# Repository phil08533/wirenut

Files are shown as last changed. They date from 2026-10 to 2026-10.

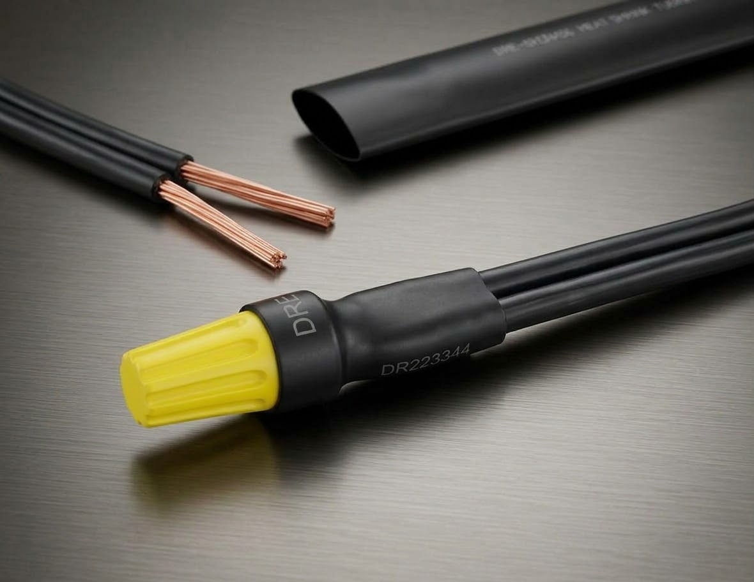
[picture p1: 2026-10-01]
IMAGES/reference_installed_on_wire_with_tubing.jpg

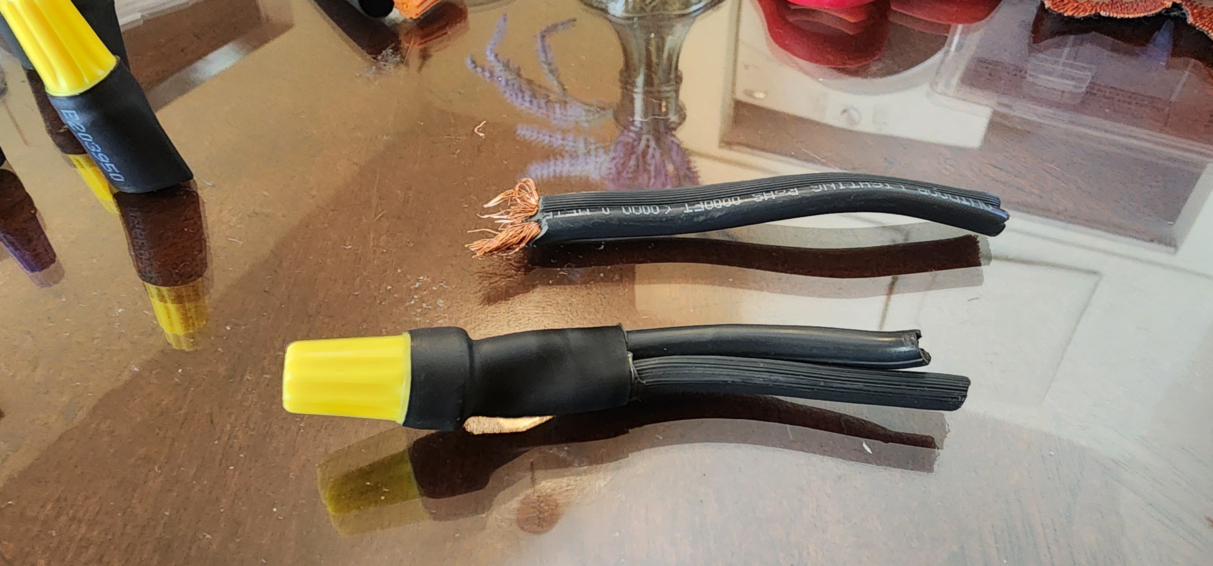
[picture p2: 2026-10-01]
IMAGES/original_installed_on_zip_cord.jpg

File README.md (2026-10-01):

# Waterproof Heat-Shrink Wire Nut — OEM Design Package

**Product:** Twist-on wire connector with integrated adhesive-lined heat-shrink waterproof sealing system.
**Primary market:** Outdoor low-voltage landscape lighting connections (12–15 V), with a path to 600 V general-purpose rating.
**IP status:** Provisional patent filed. Working prototype built (standard wire nut + heat-shrink tubing).
**Package status:** PRE-CAD. The design is NOT final. This package converts the prototype concept into a CAD-ready, quotable specification. Open items that must be resolved before tooling are tracked in `/OPEN_QUESTIONS`.

---

## Package structure

| Folder | Contents |
|---|---|
| `/PATENT` | Novelty analysis, claim language, alternative embodiments, design-around and China IP strategy, and **`05_application_draft/`** — the complete filing-ready non-provisional application (specification, 20 claims, abstract, 8 figures, forms guide) with a step-by-step pro se Patent Center filing walkthrough |
| `/ENGINEERING` | Concept trade study (Concepts A–D), selected product architecture, design calculations, materials specification |
| `/CAD_REQUIREMENTS` | Part breakdown (BOM), critical dimensions and tolerances, drawing package requirements, preliminary parametric CAD model (OpenSCAD) |
| `/MANUFACTURING` | Manufacturing plan (molding, tooling, assembly), China sourcing playbook, RFQ template, quality control plan |
| `/TESTING` | Validation test plan (UL 486D-oriented), certification roadmap |
| `/OPEN_QUESTIONS` | Questions the inventor must answer before CAD is finalized |
| `/IMAGES` | Prototype photos (AI-edited versions marked; originals to be added) |

## How to use this package

1. Answer everything in `/OPEN_QUESTIONS/01_questions_for_inventor.md`.
2. Lock the concept selection in `/ENGINEERING/01_concept_trade_study.md` (Concept A is recommended for launch; Concept B is the stronger long-term design — see the trade study).
3. Have a mechanical engineer or CAD contractor turn `/CAD_REQUIREMENTS` into production drawings (STEP + 2D PDF with GD&T).
4. Execute the IP steps in `/PATENT/04_design_around_and_ip_strategy.md` **before** sending anything to a Chinese factory (NNN agreement + non-provisional/PCT filing timing).
5. Send `/MANUFACTURING/03_rfq_template.md` plus the drawing package to 3–5 factories for quotation.
6. Validate first articles against `/TESTING/01_validation_test_plan.md`.

## Critical-path warnings

- **Provisional patent expires 12 months from filing.** The non-provisional application is drafted and ready in `/PATENT/05_application_draft/` — follow `00_pro_se_filing_walkthrough.md` to file it yourself before that date, and ideally before disclosure to any factory.
- **Never share this package with a Chinese supplier without a signed NNN agreement** (non-disclosure, non-use, non-circumvention, Chinese-law, Chinese-language). An ordinary US NDA is close to worthless in China.
- **UL 486D (Sealed Wire Connector Systems) is the certification that makes this product sellable** through distribution in the US. Design decisions in this package are made with 486D requirements in mind.

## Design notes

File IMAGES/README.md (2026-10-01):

# Prototype Images

Photos of the inventor's own prototypes: a standard twist-on wire nut combined with separately purchased heat-shrink tubing (parts from Harbor Freight).

## Originals (use these for filings, test records, and pitches)

| File | Shows |
|---|---|
| `original_lineup_prototypes.jpg` | Yellow (large) and blue (small) wire nuts with shrunk-on black heat-shrink sleeves, next to loose tubing and a lighter used for shrinking. |
| `original_installed_on_zip_cord.jpg` | Yellow wire nut with shrunk-on sleeve over spliced landscape-lighting zip cord, beside a stripped length of the same cord. |

The printed text on the sleeves (e.g. "E203950") is real. It is a UL file number printed by the tubing manufacturer and covers the tubing as a component only. It does NOT mean the finished connector is UL-listed.

## AI-edited versions

`reference_*.jpg` are the originals run through an AI image editor to look like studio shots. Use for mockups only, never for filings, test records, or buyer pitches.

TODO: record the date each original photo was taken.

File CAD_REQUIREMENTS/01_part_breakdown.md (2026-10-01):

# Part Breakdown / Engineering BOM

Assembly: **WNW-XX Waterproof Wire Nut, sealed twist-on connector** (XX = Y, R, XL)

## Top-level BOM (Concept A launch configuration)

| Item | Part no. | Description | Qty | Make/Buy | Drawing needed |
|---|---|---|---|---|---|
| 1 | WNW-XX-100 | Wire nut, twist-on, UL 486C listed | 1 | BUY | Source-control drawing (envelope + spec, not detail) |
| 2 | WNW-XX-200 | Sleeve, heat shrink, dual-wall 4:1, cut to length | 1 | BUY (cut by factory) | Detail drawing (tube spec + cut length + tolerance) |
| 3 | WNW-XX-000 | Assembly, sleeve tacked to nut | — | MAKE | Assembly drawing + tack process spec |
| 4 | WNW-PKG-25 | Bag, printed, 25-count | 1/25 | BUY | Artwork file |
| 5 | WNW-INS-01 | Instruction insert | 1/bag | BUY | Artwork file |

## Concept B additions (gen-2 — model now for patent figures, tool later)

| Item | Part no. | Description | Qty | Make/Buy |
|---|---|---|---|---|
| 6 | WNW-XX-110 | Shell, molded PA66, integral shrink-anchor skirt (annular barb ring + extended skirt) | 1 | MAKE (injection mold) |
| 7 | WNW-XX-120 | Spring, square-wire, tapered coil | 1 | BUY |

## Concept D additions (backup)

| Item | Part no. | Description | Qty | Make/Buy |
|---|---|---|---|---|
| 8 | WNW-XX-130 | Collar, snap-on shrink anchor, PA66 | 1 | MAKE (small mold) |

## Part-numbering and revision rules

- 7-segment: family (WNW) – size (Y/R/XL) – item (3 digit). Revisions letter-coded (A, B, …); any dimension change after tooling = new revision + PPAP-style re-approval.
- CAD file names must match part numbers exactly. One part per file; assembly files reference, never embed.

## Deliverable CAD file set (what the CAD contractor must produce)

| File | Format | Purpose |
|---|---|---|
| WNW-XX-000 assembly | STEP AP214 + native (SolidWorks preferred) | OEM quoting, tooling DFM |
| WNW-XX-100 envelope | STEP + PDF drawing | Source control for purchased nut |
| WNW-XX-200 detail | PDF drawing | Tube cut spec |
| WNW-XX-110 (Concept B shell) | STEP + PDF with full GD&T | Patent figures now; mold quote later |
| Exploded view | PDF + high-res PNG | Patent figures, instructions, marketing |
| 2D installation sequence (4 panels, mirrors prototype Figures 0–3) | PDF | Instruction insert + patent method figures |

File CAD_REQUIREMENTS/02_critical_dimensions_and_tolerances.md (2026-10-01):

# Critical Dimensions & Tolerances

Status: PRELIMINARY — values marked (V) require verification against the chosen purchased nut and rated cable set before drawings are released.

Units: primary **mm**, reference inches in brackets (Chinese factories work metric; the US-inch measurements from the prototype are converted here).

## D1. Purchased wire nut — source-control envelope

| Dim | WN-Y | WN-R | WN-XL | Tol | Critical? |
|---|---|---|---|---|---|
| Base OD (skirt) | 13.72 [0.540] | 16.00 [0.630] | 18.29 [0.720] | ±0.25 | **CTQ** — sets tubing supplied ID and tack interference |
| Overall height | 24.38 [0.960] | 26.67 [1.050] | 30.48 [1.200] | ±0.50 | No |
| Tip OD | 3.81 [0.150] | 4.57 [0.180] | 5.08 [0.200] | ±0.30 | No |
| Internal bore at base | 4.57 [0.180] | 5.59 [0.220] | 6.60 [0.260] | ±0.15 | **CTQ** — wire capacity |
| Internal taper angle | 6.5° | 6.5° | 6.5° | ±0.5° | **CTQ** — spring engagement |
| Skirt cylindrical band height (tack landing) | ≥ 6.0 | ≥ 6.0 | ≥ 7.0 | min | **CTQ** — tack zone must land on cylinder, not on wings |
| Wing/rib lowest point above skirt bottom | ≥ 7.0 | ≥ 7.0 | ≥ 8.0 | min | **CTQ** — clearance for tack tooling |

## D2. Heat-shrink sleeve (cut piece, supplied state)

| Dim | WN-Y | WN-R | WN-XL | Tol |
|---|---|---|---|---|
| Supplied ID | 16.0 | 20.0 | 24.0 | +1.0/−0 |
| Fully recovered ID (free) | ≤ 4.0 | ≤ 5.0 | ≤ 6.0 | max |
| Recovered wall (incl. adhesive) | ≥ 1.0 | ≥ 1.1 | ≥ 1.2 | min |
| Cut length | 30.0 | 33.0 | 36.0 | +1.0/−0 |
| Cut squareness | ≤ 1.0 | ≤ 1.0 | ≤ 1.0 | max deviation |

## D3. Assembly (shipped state) — CTQs measured at final QC

| Dim | Spec | Why |
|---|---|---|
| Sleeve top edge to nut top | tack zone starts 1.0 ± 0.5 mm below wing root | Wings stay usable |
| Tack zone length | 6.0 ± 1.0 (7.0 ± 1.0 XL) | Retention vs open bell |
| Bell ID after tack (at cut end) | ≥ 90% supplied ID | Wire insertion unobstructed |
| Sleeve axial retention | ≥ 20 N | Survives handling/pockets |
| Free bell length below nut mouth | ≥ 20 mm (Y), 22 (R), 24 (XL) | ≥15 mm sealed jacket length after 10% longitudinal shrink |
| Concentricity, sleeve to nut axis | ≤ 1.0 TIR | Cosmetic + even shrink |

## D4. Concept B molded shell (model now; toleranced for future tooling)

| Feature | Dim | Tol | Note |
|---|---|---|---|
| Anchor ring OD (barb crest) | skirt OD + 1.6 | ±0.10 | Tubing hooks behind this |
| Anchor groove root OD | skirt OD − 0.4 | ±0.10 | |
| Barb back-angle | 45° lead-in / 90° retention face | ±2° | Slide-on easy, pull-off hard |
| Skirt extension below standard profile | +4.0 | ±0.2 | Extra seal landing |
| Wall thickness (general) | 1.5 | ±0.1 | Moldability PA66 |
| Draft, external | ≥ 1° | min | Along mold pull |
| Draft, internal cone | taper itself (6.5°) serves as draft | — | Core pulls straight |
| Internal thread/spring geometry | copy qualified 486C design | — | Do NOT innovate here; certification risk |

## General tolerance block (for all drawings)

- Linear: ISO 2768-m (medium) unless stated.
- Molded parts: add shrinkage note — PA66 shrink 1.5–2.0%, tool maker to compensate; critical dims steel-safe.
- All CTQ dims must appear in the factory's control plan with Cpk ≥ 1.33 requirement.

## Measurement notes

- Recovered ID/wall measured per UL 224 method after 3 min at 150 °C oven.
- Retention force: pull sleeve axially off nut at 50 mm/min; record peak.

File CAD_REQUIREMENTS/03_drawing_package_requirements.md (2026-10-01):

# Drawing Package & Exploded-View Requirements

What the CAD contractor must deliver so an OEM can quote without a phone call.

## 1. Exploded view requirements

One exploded view per SKU (WNW-XX-000), isometric, axis vertical, nut tip up:

1. Wire nut (item 1) — show spring as cutaway inset.
2. Heat-shrink sleeve (item 2) — shown in supplied (expanded) state, translucent so the adhesive liner is visible as a distinct layer; callout "adhesive liner".
3. Phantom-line wire bundle entering from below (3 conductors shown).
4. Balloon numbers keyed to the BOM table on the same sheet.
5. Second state inset: "as shipped" (sleeve tacked) and "as installed" (recovered onto wires) — mirrors prototype Figures 0–3.

Also produce a **4-panel installation sequence** (strip/twist/heat/done) reusing the same models — this single set of geometry feeds the patent figures, the UL instruction insert, and packaging art.

## 2. Sheet requirements (every drawing)

- A3 landscape, third-angle projection, mm primary / inch reference.
- Title block: part no., rev, material, finish, scale, "CONFIDENTIAL — PATENT PENDING" legend.
- General tolerance block per 02_critical_dimensions_and_tolerances.md.
- CTQ dimensions boxed and flagged ◆ with note "CTQ — include in control plan, Cpk ≥ 1.33".
- Notes section must include manufacturing notes below.

## 3. Manufacturing notes to place on drawings

**WNW-XX-200 (sleeve):**
- Cut ends square within 1.0 mm; no adhesive smear on cut face.
- No slitting, printing, or handling above 60 °C prior to assembly.
- Supplier must provide UL 224 file no. and per-lot shrink-ratio coupon test.

**WNW-XX-000 (assembly):**
- Tack per process spec WNW-PS-001 (hot-air ring, 95–105 °C, 4–8 s, mandrel-supported).
- Full adhesive activation in tack zone NOT permitted (bell must remain open).
- 100% visual: sleeve position, no bridging of bell, no scorch.
- Retention audit: 20 N axial, AQL 1.0 sampling.

**WNW-XX-110 (Concept B shell, when tooled):**
- PA66, UL 94 V-2 min, UL-recognized resin (f1 outdoor grade if colored).
- Gate on tip face; no gate vestige > 0.2 mm; parting line flash ≤ 0.05 mm on skirt sealing band and anchor ring.
- Spring insertion after molding; torque-out and pull test per UL 486C.

## 4. File deliverables

| Deliverable | Format |
|---|---|
| 3D models | Native (SolidWorks 2022+ preferred) + STEP AP214 |
| 2D drawings | PDF + native |
| Exploded/sequence art | PDF + PNG (3000 px) |
| Patent-figure line art | Derived from CAD, black line art, no shading (patent draftsman can convert) |

## 5. Preliminary geometry in this repo

`wirenut_preliminary.scad` (OpenSCAD, parametric, all three SKUs + Concept B anchor ring) is included as a **starting reference only** — it encodes the target dimensions so the CAD contractor starts from numbers, not a sketch. It is not a production model: no spring geometry, no draft analysis, purchased-nut envelope only.

Render:  `openscad -D 'sku="XL"' -o wnw-xl.stl wirenut_preliminary.scad`

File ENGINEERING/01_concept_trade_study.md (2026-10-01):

# Concept Trade Study — Waterproof Sealing System Architecture

Question: **How should the waterproof heat-shrink system attach to the wire nut?**

Four concepts evaluated. Scoring: 1 (worst) to 5 (best). Weighting reflects the stated goal: a product that installs like a normal wire nut, seals reliably, and can be mass produced and quoted by an OEM quickly.

---

## Concept A — Pre-installed heat-shrink sleeve on a standard (purchased) wire nut

Adhesive-lined heat-shrink tubing is factory-installed over the skirt of an off-the-shelf UL-listed wire nut and extends past the wire entry. Installer twists the nut on as normal, then heats the sleeve (lighter, mini-torch, or heat gun). Adhesive flows around the wire jackets and the nut skirt, forming the seal and strain relief. **This is the prototype as built (Figures 0–3).**

- The tubing must be retained on the nut before shrinking. Options: (1) partial factory pre-shrink of the top ~1/4 of the sleeve onto the nut skirt ("tacked" state — this is what the prototype drawing shows), (2) a bead of the same adhesive, or (3) buying nuts with a molded skirt lip and pre-shrinking over it.
- No custom plastic tooling. The only custom items are the cut-to-length tubing spec and the assembly fixture.

| Criterion | Score | Notes |
|---|---|---|
| Manufacturing cost | 5 | No injection mold. Purchased nut ($0.02–0.05) + tubing ($0.04–0.10) + assembly labor/fixture. Landed COGS est. $0.10–0.20/unit at 100k volume. |
| Patent strength | 3 | Combination of known elements; strength depends on claiming the pre-assembled/tacked state, retention feature, and geometry (see /PATENT). Easier to design around than B. |
| Ease of assembly (factory) | 4 | Cut tube, slide over nut, partial pre-shrink in fixture (hot air ring or IR oven), inspect. Simple semi-automated line. |
| Factory complexity | 5 | Any cable-accessory or heat-shrink converter in China can do this. No mold trial, no resin qualification. |
| Installer experience | 4 | Identical to a wire nut + one heating step. |
| Certification path | 3 | The purchased nut is already UL 486C listed; the *sealed system* still needs UL 486D testing as a new product. Using a listed nut shortens testing. |

**Total (unweighted): 24/30 — RECOMMENDED FOR LAUNCH.**

## Concept B — Custom-molded wire nut with integral shrink-anchor skirt

A custom injection-molded nut (own tooling, own spring insert) whose lower skirt is extended and features a molded retention profile — an annular barb/groove ring — specifically shaped to anchor adhesive-lined heat shrink. Tubing is factory-installed over the anchor ring.

| Criterion | Score | Notes |
|---|---|---|
| Manufacturing cost | 3 | Mold: $8k–25k (multi-cavity), spring sourcing, insert or post-assembly of spring. COGS est. $0.08–0.15 at volume — cheaper per unit than A eventually, but high NRE. |
| Patent strength | 5 | The molded anchor geometry is a claimable structural feature; hardest to design around. |
| Ease of assembly | 4 | Same tubing operation as A, but retention is positive (mechanical) — more robust process window. |
| Factory complexity | 3 | Needs a molder + spring insertion + shrink assembly. Standard for Yueqing-area connector factories but adds mold trials, DFM loops. |
| Installer experience | 4 | Same as A. |
| Certification path | 2 | Entire connector must pass UL 486C **and** 486D from scratch (spring design, flammability, torque tests). |

**Total: 21/30 — RECOMMENDED AS GENERATION 2** and as the **primary patent embodiment** (file claims covering it now even though launch uses A).

## Concept C — Fully custom molded waterproof housing (no heat shrink)

A custom housing sealing by mechanical means — e.g., silicone-gel pre-fill, twist-compressed grommet, or O-ring cap. No heat step.

| Criterion | Score | Notes |
|---|---|---|
| Manufacturing cost | 2 | Multiple molded parts, gel dispensing or elastomer overmold; COGS $0.20–0.40. |
| Patent strength | 1 | Crowded prior art: gel-filled twist connectors (King DryConn), 3M DBY/DBR direct-bury kits, WAGO gel boxes. High freedom-to-operate risk. |
| Ease of assembly | 2 | Gel dispensing lines or multi-part assembly. |
| Factory complexity | 2 | Most complex of the four. |
| Installer experience | 3 | No heat needed (a plus), but gel is messy and re-entry is unpleasant. |
| Certification path | 3 | Well-trodden 486D territory. |

**Total: 13/30 — REJECTED.** This is where the entrenched competition already lives; it abandons the invention's differentiator.

## Concept D — Standard wire nut + separate custom molded sleeve adapter + heat shrink

A small molded collar snaps over a standard nut's skirt; the collar carries the shrink-anchor profile and the pre-installed tubing.

| Criterion | Score | Notes |
|---|---|---|
| Manufacturing cost | 3 | Small simple mold ($3k–8k) + purchased nut + tubing; COGS $0.13–0.25. |
| Patent strength | 4 | The adapter collar is a distinct, claimable article ("retrofit" claims are valuable — the collar could even be sold alone). |
| Ease of assembly | 3 | One extra snap-on operation; collar-to-nut fit depends on the purchased nut's tolerances (risk: nut vendor changes skirt geometry). |
| Factory complexity | 4 | Simple mold + assembly. |
| Installer experience | 4 | Same as A. |
| Certification path | 3 | Similar to A. |

**Total: 21/30 — STRONG BACKUP.** Choose D over A if pre-shrink tacking proves unreliable in process trials, or if a retrofit SKU (collar sold separately) is commercially interesting.

---

## Recommendation

1. **Launch with Concept A** (matches the working prototype, zero mold NRE, fastest to first article and UL 486D submission).
2. **Draft the patent around Concept B's anchor geometry as the primary embodiment**, with A and D as alternative embodiments, so the IP covers where the product will go, not just where it starts.
3. Run a **process trial during factory sampling**: if the pre-shrink tack on a smooth purchased-nut skirt slips in drop/handling tests, switch to Concept D's collar without changing the customer-facing product.

## Decision log

| Date | Decision | Status |
|---|---|---|
| — | Concept selection (A vs D for launch) | OPEN — pending inventor sign-off and process trial |
| — | Gen-2 custom nut (Concept B) go/no-go | OPEN — revisit after first 100k units |

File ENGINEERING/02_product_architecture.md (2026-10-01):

# Product Architecture — Concept A (Launch Configuration)

Status: PRELIMINARY — dimensions and features below are engineering targets derived from the prototype and measurement set. Final values require answers in `/OPEN_QUESTIONS` and factory DFM feedback.

## Product family (3 SKUs)

| SKU | Base nut (reference) | Nut base OD | Nut height | Wire range | Typical use |
|---|---|---|---|---|---|
| WN-Y (Yellow) | Standard yellow 74B-type | 0.54 in / 13.7 mm | 0.96 in / 24.4 mm | min 2×#18, max 4×#14+1×#18 | Fixture leads to run wire |
| WN-R (Red) | Standard red 76B-type | 0.63 in / 16.0 mm | 1.05 in / 26.7 mm | min 2×#14, max 2×#10+1×#12 | Main run splices |
| WN-XL (Oversized, custom target) | New size | 0.72 in / 18.3 mm | 1.20 in / 30.5 mm | up to 3×#10 | Heavy 10 ga landscape runs |

Note: WN-XL exceeds common off-the-shelf twist-on capacity for 3×#10; it may require a purchased gray/blue large-capacity nut (e.g., 454-type) or become the first custom-molded part (pulls Concept B forward for this SKU only). Flagged in `/OPEN_QUESTIONS`.

## Assembly stack (as shipped)

```
        ┌────────────────┐
        │  WIRE NUT      │  ← purchased, UL 486C listed, spring-insert twist-on
        │  (cone body)   │
   ┌────┴────────────────┴────┐
   │  HEAT-SHRINK SLEEVE      │  ← adhesive-lined polyolefin, 3:1 or 4:1
   │  upper 25% factory-tacked│     upper zone pre-shrunk onto nut skirt
   │  onto nut skirt          │
   │                          │
   │  lower 75% at supplied ID│  ← open "bell" that the wire bundle passes
   │  (free, unshrunk)        │     through during twist-on
   └──────────────────────────┘
```

## Functional description

1. **Shipped state (Figure 0/1):** sleeve is captive on the nut. The open lower bell is large enough that the installer can insert and twist wires exactly like a bare wire nut. Nothing loose, nothing to lose.
2. **Installation:** strip wires per nut spec, twist nut on to full torque. Sleeve does not interfere (bell ID > max bundle + fingers clearance).
3. **Sealing (Figure 2):** installer applies heat (lighter/torch/heat gun, ~120 °C shrink). Sleeve recovers radially onto the wire jackets; the internal hot-melt adhesive (activates ~80 °C) flows into the wire interstices and bonds to nut skirt and wire insulation.
4. **Sealed state (Figure 3):** continuous adhesive seal from nut skirt to ~20 mm down the wire jackets. Adhesive fillet + recovered tubing provide strain relief (bundle flexure is carried by the tubing, not the twisted joint).

## Key design features and their functions

| Feature | Function | Design driver |
|---|---|---|
| Adhesive-lined tubing (not single-wall) | Moisture seal; fills gaps between individual wires | UL 486D moisture ingress; single-wall tubing does NOT seal multi-wire bundles |
| Factory tack zone (upper 25%) | Captive sleeve; correct axial position guaranteed | Assembly repeatability; the installer never positions the tube |
| Tack onto nut *skirt*, below wing/rib zone | Keeps grip wings usable for twist-on torque | Install must feel like a normal wire nut |
| Sleeve overhang past wire entry: ≥ 0.9 in / 23 mm free length | ≥ 15 mm of sealed length on wire jackets after longitudinal shrinkage (~10%) | Seal length and strain relief |
| Shrink ratio 3:1 minimum (4:1 for WN-Y and WN-XL) | Must recover from over-nut-skirt ID down to smallest 2-wire bundle | See calculations file |
| Adhesive: EVA-based hot melt, lap-shear ≥ 1.4 MPa on PVC/PE | Bond to wire insulation types used in landscape cable | Direct-bury cable jackets are PE — harder to bond than PVC; verify |
| Tubing UV-stabilized (carbon-black loaded), operating −40…+125 °C | Outdoor exposure | Outdoor/UL 746C(f1)-equivalent weathering |
| Optional: temperature-indicating paint stripe on sleeve | Changes color at full recovery temperature — visual "done" signal | Reduces under-heating field failures; also a patentable feature |

## Interfaces

- **Nut ↔ sleeve:** friction + adhesive tack from factory pre-shrink. Retention spec: sleeve shall not displace under 20 N axial pull or 1 m drop onto concrete (pre-installation).
- **Sleeve ↔ wires:** recovered tubing + adhesive. Seal spec: pass 486D water immersion; pull-out per UL 486C table for the wire combination.
- **Installer heat source:** must fully recover with a butane lighter in ≤ 15 s without scorching. Tubing wall selected accordingly (thin-wall 4:1 preferred over heavy dual-wall).

## What is intentionally NOT decided yet

- Purchased-nut vendor and exact model (drives skirt geometry and tack process window).
- Whether WN-XL uses a purchased nut or the first custom mold.
- Sleeve color/branding (carbon black is best for UV; color requires UV-stable pigment qualification).
- Temperature-indicator stripe: include in v1 or hold for v2.

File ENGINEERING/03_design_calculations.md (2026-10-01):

# Design Calculations — Sleeve Sizing, Shrink Ratios, Seal Geometry

Status: PRELIMINARY. Wire ODs are nominal THHN/landscape-cable values and MUST be verified against the actual cable types the product will be rated for (see /OPEN_QUESTIONS — landscape lighting cable has much thicker insulation than THHN).

## 1. Wire bundle diameters

Circumscribed diameter of n equal circles of diameter d:
- 2 wires: 2.000 × d
- 3 wires: 2.155 × d
- 4 wires: 2.414 × d
- 5 wires: 2.701 × d

Nominal insulated ODs (THHN, approximate — verify):

| AWG | OD (in) | OD (mm) |
|---|---|---|
| #18 | 0.105 | 2.7 |
| #14 | 0.111 | 2.8 |
| #12 | 0.128 | 3.3 |
| #10 | 0.164 | 4.2 |

Typical low-voltage direct-burial landscape cable (e.g., 12/2, 10/2 zip-style) single-conductor leg OD is larger: ~0.19–0.24 in (4.8–6.1 mm) per leg. **This, not THHN, is probably the governing case — confirm.**

Governing bundle diameters per SKU (THHN basis):

| SKU | Min bundle | Dia | Max bundle | Dia |
|---|---|---|---|---|
| WN-Y | 2×#18 | 0.210 in / 5.3 mm | 4×#14 + 1×#18 | ≈0.30 in / 7.6 mm |
| WN-R | 2×#14 | 0.222 in / 5.6 mm | 2×#10 + 1×#12 | ≈0.36 in / 9.1 mm |
| WN-XL | 2×#12 (assumed) | 0.256 in / 6.5 mm | 3×#10 | 0.353 in / 9.0 mm |

## 2. Required shrink ratio

The sleeve must satisfy BOTH:
- **Supplied (expanded) ID** ≥ nut skirt OD + 0.5–1.0 mm assembly clearance (it is slid over the nut base at the factory).
- **Fully recovered ID** ≤ 0.85 × minimum bundle diameter (need residual hoop compression; adhesive fills the rest).

| SKU | Nut base OD | Required supplied ID | Min bundle | Required recovered ID | Required ratio |
|---|---|---|---|---|---|
| WN-Y | 13.7 mm | ≥ 14.5 mm | 5.3 mm | ≤ 4.5 mm | ≥ 3.2 : 1 → **use 4:1** |
| WN-R | 16.0 mm | ≥ 17.0 mm | 5.6 mm | ≤ 4.8 mm | ≥ 3.5 : 1 → **use 4:1** |
| WN-XL | 18.3 mm | ≥ 19.5 mm | 6.5 mm | ≤ 5.5 mm | ≥ 3.5 : 1 → **use 4:1** |

Conclusion: **4:1 adhesive-lined polyolefin across all SKUs.** Standard commercial 4:1 dual-wall sizes that fit:

| SKU | Candidate tubing (supplied/recovered ID) | Wall (recovered) |
|---|---|---|
| WN-Y | 16 / 4 mm | ~1.0 mm |
| WN-R | 20 / 5 mm | ~1.1 mm |
| WN-XL | 24 / 6 mm | ~1.2 mm |

Notes:
- 3:1 tubing only works if the minimum wire configuration is restricted (e.g., WN-R limited to ≥ 3×#14). That trade-off is a labeling/marketing decision — see /OPEN_QUESTIONS.
- If the minimum config is 2 legs of direct-burial cable (~2 × 5.5 mm = 11 mm bundle), 3:1 20/6.5 mm tubing suffices for WN-R/XL and cost drops ~30%. **This is why the rated-cable question is the single most important open item.**

## 3. Sleeve length

Requirements: cover skirt tack zone (6 mm) + bridge the wire-entry mouth (≈ 4 mm) + sealed length on jacket (≥ 15 mm) + longitudinal shrinkage allowance (10%).

| SKU | Cut length (supplied) | Tack zone | Free bell length |
|---|---|---|---|
| WN-Y | 30 mm +1/−0 | 6 mm | 24 mm |
| WN-R | 33 mm +1/−0 | 6 mm | 27 mm |
| WN-XL | 36 mm +1/−0 | 7 mm | 29 mm |

## 4. Thermal compatibility check

| Item | Temperature | OK? |
|---|---|---|
| Tubing shrink onset / full recovery | ~90 °C / ~120 °C | — |
| Adhesive activation | ~80 °C | — |
| Wire nut shell (PA66) melt / short-term | 255 °C / 180 °C | ✅ margin vs 120 °C |
| Wire nut shell if PP | melt 160 °C, softens ~120 °C | ⚠️ marginal — prefer PA66 nuts; verify purchased nut resin |
| PVC wire insulation rating | 105 °C (THHN) | ⚠️ brief excursion during shrink is industry-accepted (same as any heat-shrink splice), but flame dwell must be limited — instructions requirement |
| PE direct-burial jacket | softens ~105–120 °C | ⚠️ same — keep flame moving |

Action: purchased-nut spec must state shell resin = PA66 (or verified ≥150 °C short-term). This goes in the incoming-material spec (/MANUFACTURING/04).

## 5. Pre-tack process window (factory)

- Tack zone target recovery: 30–50% diametral (snug on skirt, adhesive *not* fully activated — full activation would glue the bell shut edge).
- Process: hot-air ring or IR oven, 95–105 °C zone, 4–8 s, nut held tip-down on mandrel so the bell hangs free.
- Verification: 20 N axial retention; bell ID after tack ≥ 90% of supplied ID.

## 6. Strain relief estimate

Recovered dual-wall on the bundle acts as a cantilever sleeve. With 15 mm sealed length and ~1 mm wall polyolefin + adhesive fillet, expected pull-out contribution ≥ 50 N and flex-life improvement >10× vs bare nut (to be validated per /TESTING — UL 486C pull-out table governs the pass/fail numbers, e.g., #10 requires 80 lbf on the connector joint itself).

## 7. Cost model (rough, 100k units/SKU/yr, China EXW)

| Element | WN-Y | WN-R | WN-XL |
|---|---|---|---|
| Purchased nut | $0.025 | $0.035 | $0.06 (large nut) |
| Tubing (4:1 dual wall, cut) | $0.06 | $0.08 | $0.11 |
| Assembly + QC | $0.02 | $0.02 | $0.02 |
| Packaging (bag of 25 + card) | $0.01 | $0.01 | $0.015 |
| **EXW unit** | **≈$0.12** | **≈$0.15** | **≈$0.21** |

Retail comparators: gel-filled waterproof nuts sell at $0.50–1.20/unit street price — healthy margin room. Refine with real quotes via /MANUFACTURING/03_rfq_template.md.

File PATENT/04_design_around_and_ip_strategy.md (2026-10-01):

# Design-Around Protection & IP Strategy

## How a competitor will try to design around you — and the counter

| Design-around attempt | Counter (already in this package) |
|---|---|
| Ship nut and sleeve **separately in one package** ("kit") to dodge the captive/unitary claim | Kit embodiment #26 + method claim 3 (covers the twist-then-heat use regardless of shipped state) |
| Use **cold-shrink** sleeve instead of heat shrink | Embodiment #14 + draft claims using "heat-recoverable **or** elastically-recoverable" language where counsel allows |
| Use **mastic band** instead of adhesive lining | Embodiment #9; claim "sealant lining" generically in at least one independent claim |
| Put the sleeve on a **push-in (WAGO-style) connector** instead of a twist-on | Embodiment #17 — instruct counsel to draft at least one claim to "an electrical connector" generically |
| Change retention: glue bead, clamp ring, overmold | Embodiments #5, #6, #7 |
| Stepped/top-hat sleeve to avoid your shrink-ratio dependent claims | Embodiment #10 (and keep ratio limits in *dependent* claims only) |
| Manufacture and sell only in China / export around US patent | CN utility model + CN customs IP recordation (below) |

## Filing strategy & timeline

| When | Action | Why |
|---|---|---|
| NOW | Confirm provisional filing date; calendar the 12-month deadline with 60-day buffer | Everything hangs on this date |
| Before factory contact | Non-provisional drafted (or at least NNN executed + disclosure limited to provisional content) | Unprotected disclosure = free gift |
| ≤ month 12 | File US non-provisional claiming priority + PCT (or direct CN filing) | Preserves US + international rights |
| With CN counsel | **CN utility model** in parallel (grants in ~7–12 months, no substantive exam, cheap) | The only fast, enforceable right where your factory lives; deters the factory itself |
| After CN grant | Record with China customs (GACC) | Enables seizure of infringing exports at Chinese ports |
| Anytime (cheap) | US + CN **design patent** on shipped-state appearance | Blocks lookalike knockoffs on Amazon; Amazon takedowns accept design patents readily |
| Now | US + CN **trademark** on the brand name | China is first-to-file; squatters watch new US brands |

## Practical enforcement reality

- The utility patent's biggest commercial value at your stage: **Amazon Brand Registry / IP takedowns** and deterring US distributors from stocking clones — not litigation.
- Mark packaging "Patent Pending" now; after grant, virtual marking (URL) per 35 USC 287.
- Keep an evidence file: dated prototype photos (the Figure 0–3 sheet), lab notebook, factory correspondence — supports priority disputes and derivation claims.

## Trade-secret layer (complements patents)

Keep OUT of the patent (and out of any single factory's hands if possible):
- The exact tack process window (temperature/time/fixture design) — process trade secret.
- Adhesive formulation selection rationale and supplier qualification data.
- The QC golden-sample criteria.

## Budget

| Item | Est. |
|---|---|
| Prior-art + FTO search | $2–4k |
| US non-provisional (attorney) | $8–15k |
| PCT filing | $4–5k (defers national decisions 30 months) |
| CN utility model | $1–2k |
| US design patent | $1.5–2.5k |
| US + CN trademarks | $1–2.5k |

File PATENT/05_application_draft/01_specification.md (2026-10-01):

# UTILITY PATENT APPLICATION — SPECIFICATION

> Formatting note (delete before filing): This document follows 37 CFR 1.77 section order. Convert to DOCX for filing (avoids the non-DOCX surcharge): 1.5 or double spacing, 12-pt font, paragraph numbering [0001]… as shown, page numbers centered bottom. Claims and Abstract are filed as parts of the same specification document but must each start on a new page — they live in `02_claims.md` and `03_abstract.md`.

---

# SEALABLE TWIST-ON WIRE CONNECTOR WITH CAPTIVE HEAT-RECOVERABLE SLEEVE

## CROSS-REFERENCE TO RELATED APPLICATIONS

[0001] This application claims the benefit of U.S. Provisional Patent Application No. **[PLACEHOLDER — 63/XXX,XXX]**, filed **[PLACEHOLDER — DATE]**, titled **[PLACEHOLDER — provisional title]**, the entire contents of which are incorporated herein by reference.

## FIELD OF THE INVENTION

[0002] The present disclosure relates to electrical connectors, and more particularly to twist-on wire connectors provided with an integrated, heat-recoverable environmental sealing system for making moisture-resistant electrical splices, for example in outdoor low-voltage landscape lighting installations.

## BACKGROUND

[0003] Twist-on wire connectors, commonly called wire nuts, are among the most widely used devices for splicing electrical conductors. A typical twist-on connector includes a generally conical insulating shell containing a tapered helical spring. Stripped conductor ends are inserted into the open end of the shell, and the connector is rotated so that the spring draws the conductors together into a twisted, gas-tight mechanical and electrical joint. Twist-on connectors are inexpensive, fast to install, require no tools, and are familiar to virtually every electrician and homeowner.

[0004] Standard twist-on connectors, however, provide no environmental seal. The open end of the shell leaves the splice exposed to moisture. In outdoor applications — landscape lighting, irrigation systems, well pumps, exterior fixtures — moisture ingress causes corrosion of the conductors and spring, increased contact resistance, galvanic degradation, nuisance failures, and, in low-voltage lighting systems, voltage drop and flickering.

[0005] Several approaches exist for sealing such splices, each with significant shortcomings. (a) Electrical tape wrapped over the connector and wires is slow, skill-dependent, unsightly, and unwinds or admits moisture over time. (b) Dielectric grease applied into the connector cavity is messy and provides no mechanical retention of the seal. (c) Pre-filled sealant connectors, in which the shell is factory-filled with silicone gel, provide useful moisture resistance but are messy to install and re-enter, provide little or no strain relief to the conductor bundle, and the gel can be displaced during installation, particularly with multiple large conductors. (d) Heat-shrinkable tubing with an adhesive lining is highly effective for sealing linear splices such as crimped butt connectors, but is fundamentally incompatible with twist-on connectors as conventionally supplied: the tubing must be threaded onto a conductor **before** the joint is made, must then be slid over the completed joint, and a twist-on connector is substantially larger in diameter than the conductor bundle, so tubing sized to pass over the connector cannot recover tightly onto the conductors unless a very high shrink ratio is used and the tubing is correctly positioned — a multi-step, error-prone process requiring the installer to select, cut, thread, park, position, and recover a separate component. In addition, the rotation of a twist-on connector during installation tends to displace or wind up any loose sleeve placed over it beforehand.

[0006] There accordingly exists a need for a wire connector that installs with the identical, familiar motion of a standard twist-on connector — with nothing extra to select, thread, or position — and that can then be environmentally sealed in a single additional step, providing both moisture sealing and strain relief, and that is manufacturable at low cost at scale.

## SUMMARY

[0007] The present disclosure provides a sealable electrical connector assembly in which a heat-recoverable, sealant-lined sleeve is factory-installed on a twist-on wire connector in a partially recovered, captive state. A first portion of the sleeve is recovered (or otherwise retained) onto an exterior skirt of the connector shell, permanently locating the sleeve on the connector. A second portion of the sleeve extends beyond the open end of the connector in a substantially unrecovered state, defining an open entry bell. Because the bell's inner diameter substantially exceeds the conductor bundle diameter, conductors are inserted and the connector is rotated exactly as with a standard twist-on connector; the captive sleeve neither obstructs insertion nor winds up during rotation. After the twisted joint is made, the installer applies heat; the second portion recovers radially onto the conductor insulation, and the sealant lining flows into the interstices between conductors and bonds to both the shell and the conductor insulation, forming a continuous environmental seal and a strain-relieving collar in one step.

[0008] In some embodiments the connector shell includes a molded annular retention formation — for example a barb ring having an inclined lead-in surface and a transverse retention surface — dimensioned to mechanically retain the sleeve against axial displacement and against the torsional loads of rotational installation. In other embodiments the sleeve is carried by a collar engageable with the skirt of a standard connector shell, permitting the sealing system to be applied to existing connector designs. Further embodiments include a stepped-diameter sleeve reducing the required shrink ratio; a thermochromic indicator that changes appearance when full recovery temperature has been reached, giving the installer positive visual confirmation of a complete seal; elastically recoverable (cold-shrink) sleeves held expanded by a removable core; and mastic or other sealant linings.

[0009] The assembly is supplied as a unitary article. Installation requires no additional parts, no threading of tubing before splicing, and no repositioning; the only step added to conventional practice is the application of heat. Embodiments described herein are dimensioned to seal conductor combinations from two 18 AWG conductors up to three 10 AWG conductors, including dissimilar-size combinations common in landscape lighting.

## BRIEF DESCRIPTION OF THE DRAWINGS

[0010] FIG. 1 is an exploded perspective view of a sealable connector assembly according to a first embodiment, showing a twist-on wire connector, a heat-recoverable sleeve, and a plurality of conductors.

[0011] FIG. 2 is a longitudinal cross-sectional view of the assembly of FIG. 1 in the as-supplied (shipped) state, showing the first sleeve portion recovered onto the shell skirt and the second sleeve portion defining an open entry bell.

[0012] FIG. 3 is a longitudinal cross-sectional view of the assembly of FIG. 1 in the installed and sealed state, recovered onto the conductors.

[0013] FIG. 4 is an enlarged fragmentary cross-sectional view of a second embodiment in which the connector shell includes an annular retention formation.

[0014] FIG. 5 is a cross-sectional view of a third embodiment in which the sleeve is carried by a collar engageable with the skirt of a standard twist-on connector.

[0015] FIGS. 6A–6D are sequential elevation views illustrating a method of forming a sealed connection using the assembly: FIG. 6A, conductor insertion; FIG. 6B, rotational installation; FIG. 6C, application of heat; FIG. 6D, the completed sealed connection.

[0016] FIG. 7 is a cross-sectional view of a further embodiment employing a stepped-diameter sleeve.

[0017] FIG. 8 is an elevation view of a further embodiment including a thermochromic recovery indicator.

## DETAILED DESCRIPTION

### First embodiment — captive pre-tacked sleeve (FIGS. 1–3)

[0018] Referring to FIGS. 1 and 2, a sealable connector assembly 10 comprises a twist-on wire connector 20 and a heat-recoverable sleeve 40 captively retained thereon. The connector 20 comprises an insulating shell 22 — for example molded polyamide — having an open end 24 communicating with an internal tapered cavity 26 in which a tapered helical spring 28 of square-section steel wire is retained. The shell 22 has a generally conical exterior narrowing from a base skirt portion 30 adjacent the open end 24 toward a closed tip, and carries external grip formations 32 (wings or ribs) by which installation torque is applied. The connector 20 may be of conventional construction and, in some embodiments, is a commercially available connector certified to applicable wire-connector standards.

[0019] The sleeve 40 is a tube of heat-recoverable, cross-linked polyolefin having an interior sealant lining 46, for example a hot-melt adhesive having an activation temperature (e.g., about 80 °C) below the full-recovery temperature of the sleeve (e.g., about 120 °C). The sleeve 40 comprises a first portion 42 and a second portion 44. The first portion 42 is partially recovered onto the skirt portion 30, gripping the shell and axially and rotationally locating the sleeve 40 on the connector 20. In this embodiment the partial recovery of the first portion 42 is performed during manufacture ("tacking"), for example by directing heated air at only the first portion while the second portion is shielded or spaced from the heat source, such that the sealant lining 46 within the first portion is not fully activated and the second portion 44 remains substantially at its expanded, as-supplied diameter.

[0020] The first portion 42 is recovered onto a substantially cylindrical band of the skirt portion 30 located below the grip formations 32, so that the grip formations remain exposed and fully usable for rotational installation. In one embodiment the first portion has an axial length of about 6 mm to about 7 mm and begins about 1 mm below the root of the grip formations 32.

[0021] The second portion 44 extends beyond the open end 24 and terminates at a distal end 48, defining an open entry bell whose inner diameter is substantially the as-supplied inner diameter of the sleeve — greater than the outer diameter of the skirt portion 30 and several times greater than the diameter of the largest rated conductor bundle. Conductors 50 having stripped ends 52 and insulation 54 are therefore insertable through the bell into the cavity 26 without contacting or displacing the sleeve, and the connector may be rotated to form the joint without the sleeve winding up, because the sleeve is fixed to the shell and rotates with it.

[0022] Referring to FIG. 3, after the twisted joint is formed, heat applied to the second portion 44 — by a lighter, torch, or hot-air tool — causes it to recover radially onto the insulation 54 of the conductors 50, forming a seal region 60 in which the activated sealant lining 46 flows into the interstices between adjacent conductors and forms a fillet 62 bonding the shell 22, the sleeve 40, and the insulation 54 into a continuous moisture barrier. The recovered second portion additionally couples bending loads on the conductor bundle into the shell rather than into the twisted joint, providing strain relief.

### Dimensional relationships

[0023] The sleeve is selected such that (a) its as-supplied inner diameter exceeds the outer diameter of the skirt portion 30, permitting factory assembly over the shell, and (b) its fully recovered inner diameter is no greater than about 85% of the diameter of the smallest conductor bundle the connector is rated to receive, ensuring residual hoop compression on the smallest bundle. For representative connector sizes these conditions correspond to a diametral shrink ratio of at least about 3:1, and in the embodiments tabulated below, about 4:1.

[0024] Table 1 sets forth representative, non-limiting dimensions for three embodiment sizes:

| Parameter | Size 1 | Size 2 | Size 3 |
|---|---|---|---|
| Shell base (skirt) outer diameter | 13.7 mm (0.54 in) | 16.0 mm (0.63 in) | 18.3 mm (0.72 in) |
| Shell overall height | 24.4 mm (0.96 in) | 26.7 mm (1.05 in) | 30.5 mm (1.20 in) |
| Cavity bore at open end | 4.6 mm (0.18 in) | 5.6 mm (0.22 in) | 6.6 mm (0.26 in) |
| Cavity taper angle (per side) | ~6–7° | ~6–7° | ~6–7° |
| Rated conductor range | 2×18 AWG to 4×14+1×18 AWG | 2×14 AWG to 2×10+1×12 AWG | up to 3×10 AWG |
| Sleeve as-supplied ID | 16 mm | 20 mm | 24 mm |
| Sleeve fully recovered ID | ≤ 4 mm | ≤ 5 mm | ≤ 6 mm |
| Sleeve cut length | 30 mm | 33 mm | 36 mm |
| First (tacked) portion length | 6 mm | 6 mm | 7 mm |

[0025] In embodiments, the second portion 44 is dimensioned such that, after full recovery and accounting for longitudinal shrinkage of about 10%, the sleeve extends at least about 15 mm along the conductor insulation beyond the open end 24, providing the seal region 60 with sufficient length for both sealing and strain relief.

### Second embodiment — shell with retention formation (FIG. 4)

[0026] Referring to FIG. 4, in a second embodiment the shell 22 is molded with an annular retention formation 70 on the skirt portion 30. The retention formation 70 comprises an inclined lead-in surface 72 facing away from the open end 24, over which the sleeve is slid during factory assembly, and a transverse retention surface 74 facing toward the open end, behind which the first portion 42 of the sleeve engages. In one embodiment the lead-in surface 72 is inclined at about 30° to about 60° to the shell axis and the retention surface 74 is substantially perpendicular to the shell axis, and the formation projects radially about 0.8 mm above the adjacent skirt surface. The retention formation positively resists both axial pull-off and rotational slip during installation torque, widening the manufacturing process window: with the formation 70, the first portion 42 may be recovered only lightly, or the sleeve may even be retained by the formation alone without thermal tacking. The shell of this embodiment may further include an extended skirt 76 lengthening the sealing land. The retention formation may alternatively comprise a groove, a plurality of ribs, knurling, or other surface texture performing the equivalent retaining function.

### Third embodiment — retrofit collar (FIG. 5)

[0027] Referring to FIG. 5, in a third embodiment the sleeve 40 is carried by a collar 80 having resilient engagement features 82 (for example an interference band or snap fingers) engageable with the skirt of a standard, unmodified twist-on connector 20. The collar 80 carries the retention geometry of the second embodiment, and the sleeve 40 is retained on the collar with its second portion 44 defining the entry bell as previously described. This embodiment permits the sealing system to be supplied either pre-assembled to a connector or as a separate adapter for field or factory application to existing connectors.

### Method of use (FIGS. 6A–6D)

[0028] Referring to FIGS. 6A–6D, a sealed connection is formed by: providing the assembly 10 as a unitary article; inserting stripped ends 52 of two or more conductors 50 through the open bell of the second portion 44 into the cavity 26 (FIG. 6A); rotating the connector 20 by the grip formations 32 to draw the conductors into a twisted mechanical and electrical joint, the sleeve rotating with the connector (FIG. 6B); applying heat from a heat source 110 — an open flame, hot-air tool, or other source — to the second portion 44 until it recovers onto the conductor insulation and the sealant lining activates (FIG. 6C); and allowing the assembly to cool, yielding a sealed, strain-relieved connection (FIG. 6D). Notably, steps illustrated in FIGS. 6A and 6B are identical to the installation of a conventional twist-on connector; no tubing is selected, cut, threaded, parked, or positioned by the installer.

### Further embodiments

[0029] **Stepped sleeve (FIG. 7).** The sleeve 40 may be a stepped-diameter member 100 having a smaller-diameter proximal region pre-formed to approximately the skirt diameter and a larger-diameter distal bell, reducing the shrink ratio required of the distal region and permitting use of lower-ratio, lower-cost tubing while preserving the captive, open-bell installation behavior.

[0030] **Recovery indicator (FIG. 8).** The sleeve 40 may carry a thermochromic indicator 90 — a stripe, dot, or full-surface coating — that irreversibly changes appearance upon reaching substantially the full-recovery temperature of the sleeve, providing the installer visual confirmation that sealing temperature was achieved and reducing under-heated field failures.

[0031] **Sealant variants.** The sealant lining 46 may comprise a hot-melt adhesive, a mastic band disposed within the second portion, a UV-curable or chemically activated sealant, or combinations thereof. In embodiments, the lining is confined to, or of greater thickness in, the second portion 44, so that factory tacking of the first portion does not activate sealant unnecessarily.

[0032] **Elastic (cold-shrink) variant.** The sleeve 40 may be an elastically recoverable elastomeric sleeve held in a radially expanded state by a removable core, the core extending through the second portion; withdrawal of the core after installation recovers the second portion onto the conductors without applied heat. All references herein to a "heat-recoverable" sleeve should be understood to encompass, in the alternative, such elastically recoverable sleeves except where heating is expressly recited.

[0033] **Connector variants.** While the illustrated connector is a twist-on connector with helical spring 28, the captive-sleeve sealing system may be applied to other insulation-piercing, push-in, lever-actuated, or crimp connectors having a shell with an exterior surface onto which the first portion 42 can be retained. The shell may be molded with the sleeve in place (insert molding), or the sleeve may be retained by an adhesive bead, a clamp ring, or the collar of the third embodiment.

[0034] **Materials.** In embodiments the shell 22 comprises polyamide (e.g., PA66) rated for the recovery temperature of the sleeve; the sleeve comprises cross-linked polyolefin, ultraviolet-stabilized for outdoor exposure, for example carbon-black loaded; and the sealant lining comprises an ethylene-vinyl-acetate-based hot-melt adhesive bonding to polyvinyl chloride, polyethylene, and polyamide surfaces. These materials are exemplary and non-limiting.

[0035] **Kit form.** The connector and sleeve may alternatively be supplied unassembled as a kit in a common package, the sleeve including an alignment feature cooperating with the shell to establish the captive shipped configuration described above upon assembly by the user.

[0036] The embodiments described above are illustrative. Features of any embodiment may be combined with features of any other. The scope of the invention is defined by the claims, not by the particular examples given, and equivalents of the claimed elements are intended to be embraced thereby.

---

## REFERENCE NUMERAL INDEX (drafting aid — delete before filing)

| # | Element | # | Element |
|---|---|---|---|
| 10 | sealable connector assembly | 48 | distal end of sleeve |
| 20 | twist-on wire connector | 50 | conductors |
| 22 | shell | 52 | stripped ends |
| 24 | open end | 54 | insulation |
| 26 | internal tapered cavity | 60 | seal region |
| 28 | helical spring | 62 | sealant fillet |
| 30 | skirt portion | 70 | retention formation |
| 32 | grip formations | 72 | lead-in surface |
| 40 | heat-recoverable sleeve | 74 | retention surface |
| 42 | first portion (tacked) | 76 | extended skirt |
| 44 | second portion (bell) | 80 | collar |
| 46 | sealant lining | 82 | engagement features |
| — | — | 90 | thermochromic indicator |
| — | — | 100 | stepped sleeve |
| — | — | 110 | heat source |

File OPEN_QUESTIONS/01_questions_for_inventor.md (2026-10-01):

# Open Questions for the Inventor

These must be answered before the CAD drawings are released. Items marked 🔴 block CAD; 🟡 block RFQ; 🟢 block certification/launch. Answer inline under each question and commit.

## 1. Prototype construction 🔴

1.1 Which exact wire nut brand/model did the working prototype use (brand, size/color, purchased where)?
1.2 Which exact heat-shrink tubing (brand, supplied/recovered diameter, 2:1/3:1/4:1, adhesive-lined or single-wall)?
1.3 How is the tubing attached to the nut in your prototype — pre-shrunk at the top (as Figure 0–3 suggests), glued, or just friction? Has it ever slipped off in handling?
1.4 How many prototypes built, and have any been water-tested? Results?

## 2. Heat-shrink placement 🔴

2.1 In the shipped state, how far up the nut does the tubing sit — does it cover the grip wings/ribs, or stop below them? (Drives tack-zone location; current assumption: stops below the wings so twist grip is unaffected.)
2.2 After shrinking, how much tubing length is on the wires? (Current target ≥ 15 mm — confirm against what worked.)

## 3. Sealing method 🔴

3.1 Is your prototype tubing adhesive-lined? If not: single-wall tubing will NOT pass water immersion on a multi-wire bundle — the package assumes adhesive-lined dual-wall. Confirm you accept this change.
3.2 Do you want a **re-enterable** connection (cut sleeve off, re-splice with a new unit) as a documented procedure, or is single-use acceptable? (Affects instructions and marketing, not geometry.)

## 4. Wire entry / rated conductors 🔴 — **the single most important question set**

4.1 What actual cable will customers use — THHN singles, or 2-conductor direct-burial landscape cable (12/2, 10/2)? Landscape cable legs are much fatter (~5–6 mm each); this drives shrink ratio, recovered ID, and possibly the whole tubing selection (see ENGINEERING/03 §2).
4.2 What is the **minimum** wire combination each SKU must seal? (Smallest bundle drives the required shrink ratio; if we can set min = 2×#14, tubing cost drops.)
4.3 For WN-XL (3×#10): is this THHN #10 or #10 landscape cable legs?
4.4 Must the product seal mixed combinations (e.g., 1 fat landscape leg + 1 thin fixture lead #18)? That asymmetry is the hardest seal case.

## 5. Installation process 🟡

5.1 What heat source should the instructions assume as primary: butane lighter, micro-torch, or heat gun? (Field reality for landscapers = lighter/torch; affects tubing wall spec and scorch testing.)
5.2 Acceptable install time budget for the heating step (current target ≤ 15 s)?
5.3 Should v1 include the temperature-indicator stripe ("turns black when sealed"), or hold for v2? Adds ~$0.01–0.02/unit and one supplier qualification.
5.4 Any requirement to install in rain/wet conditions? (Adhesive won't bond to wet jackets — instructions issue.)

## 6. Materials 🟡

6.1 Sleeve color: black (best UV, recommended) or match nut color (yellow/red — needs UV-stable pigment qualification, cost adder)?
6.2 Any objection to sourcing tubing from qualified Chinese makers (Woer/Volsun grade) vs TE/Panduit (2–4× cost)?
6.3 For Concept A: do you have a preferred wire-nut brand to buy, or should the factory propose its UL-listed source (cheapest, but adds a supplier-change risk clause)?

## 7. Voltage rating & claims 🟢

7.1 Target marketing claim: low-voltage only (12–30 V landscape) or full 600 V splice rating? (Nut supports 600 V; the difference is test scope and instruction wording.)
7.2 Direct-bury claim: yes/no? (Big label value for landscape; adds 486D burial testing. Recommend YES.)
7.3 Target markets beyond US: Canada (cUL — cheap adder, recommend yes)? EU (different connector culture, suggest defer)?

## 8. Business/commercial 🟢

8.1 Provisional filing date? (Sets the non-provisional deadline — everything in PATENT/04 hangs on it.)
8.2 Does the provisional describe the pre-tacked captive sleeve state and the anchor-ring variant, or only "wire nut + heat shrink" generally? (Determines how urgent the non-provisional is.)
8.3 Brand name for trademark filing (US + CN)?
8.4 Launch channel: Amazon/DTC first, or distribution/big-box? (Changes UL-vs-ETL choice and packaging.)
8.5 Budget envelope for the next 12 months? (Package assumes roughly: IP $15–25k, certification $20–45k, pilot inventory $8–12k, misc $5k.)

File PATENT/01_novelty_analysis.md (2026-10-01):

# Novelty Analysis

**Disclaimer:** Engineering analysis to prepare you for patent counsel — not legal advice. A professional prior-art/FTO search by a patent attorney is a required next step.

## Prior-art landscape (what already exists)

| Category | Examples | How it seals | Relevance |
|---|---|---|---|
| Gel/silicone pre-filled twist connectors | King Innovation DryConn, Ideal WeatherProof, Gardner Bender WeatherProof | Dielectric silicone grease pre-filled in oversized shell | Closest commercial competitors; heavily patented historically (many now expired) — crowds Concept C, not the heat-shrink approach |
| Direct-bury splice kits | 3M DBY/DBR, King DryConn Direct Bury | Wire nut inserted into a separate gel-filled tube | Two-piece, bulky, no heat |
| Heat-shrink crimp splices | NSPA/Molex "Krimpa-Seal", generic sealed butt splices | Adhesive-lined tubing over a **crimp** barrel | Establishes adhesive-lined shrink as known for *crimps* — not for twist-on connectors |
| Separate heat-shrink tubing | Any brand | Installer cuts and slides tubing **before** joining — impossible retrofit over a wire nut | Your product's pain-point story |
| Cold-shrink / mastic wraps | 3M cold shrink, tape+mastic | Elastomer or mastic | Different mechanism |

**Search terms for the professional search:** "twist-on wire connector" + "heat shrink"; "wire nut" + "sealing sleeve"; CPC classes H01R 4/22 (twisted connections), H01R 4/72 (heat-shrink connections), H02G 15/18. Expect to find *something* combining these — the question is whether it shows your specific captive pre-tacked construction.

## Features with potential novelty (ranked)

1. **Captive, factory pre-tacked sleeve in a partially-recovered state** — a twist-on connector shipped as a single unit whose adhesive-lined sleeve is partially recovered onto the connector skirt while the remainder stays expanded as an open wire-entry bell. This *shipped intermediate state* is the strongest candidate: it's structural, inspectable in an infringing product, and it's what makes the product "install like a normal wire nut."
2. **Shrink-anchor geometry on the connector shell** (Concept B): annular barb/groove ring dimensioned to retain heat-shrink tubing through twist-on torque — a claimable mechanical feature.
3. **Method of use**: twist-then-heat sealing of a twist-on connector where the sleeve is pre-positioned — method claims deter competitors' *instructions* even when parts are generic.
4. **Retrofit collar** (Concept D): snap-on adapter carrying a pre-installed sleeve for standard wire nuts.
5. **Temperature-indicating recovery stripe** on the sleeve signaling full seal — supports a dependent claim and a strong marketing feature.
6. Dimensional relationships: sleeve supplied ID ≥ skirt OD; recovered ID ≤ 0.85 × minimum rated bundle; ≥15 mm jacket seal length — useful dependent-claim fodder that maps to your measured dimension set.

## Weaknesses to expect from an examiner

- Obviousness (35 USC 103) combining a wire nut with known adhesive-lined tubing. Counters: (a) the *captive partially-recovered* construction is not shown by tubing-on-a-reel art; (b) commercial failure/absence of the combination despite decades of both elements; (c) the open-bell insertion problem (tubing must not block twist-on) is a real technical obstacle your tack geometry solves — write this problem/solution story into the spec.
- If your provisional only shows "wire nut + heat shrink" generically, the tack state, anchor ring, indicator stripe, and dimensional relations may NOT be supported — they must go into the non-provisional as new matter with its own filing date. **File soon; every month of delay is design-around exposure.**

## Freedom-to-operate flags

- Verify no live patents on adhesive-lined tubing formulations you spec (formulations are supplier's problem, but "sealed connector system" claims could reach the assembly).
- King Innovation and 3M actively defend the waterproof-connector space — the FTO search should specifically pull their live families.

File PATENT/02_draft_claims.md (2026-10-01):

# Draft Claim Language (working draft for patent counsel)

**Disclaimer:** Drafting aid for your attorney, not legal advice and not filing-ready. Claim scope decisions belong to registered patent counsel.

## Independent claim 1 — apparatus (Concept A/B, the core)

> 1. A sealable electrical connector assembly comprising:
> a twist-on wire connector having a shell with an open end for receiving a plurality of electrical conductors and a conductive spring disposed within the shell;
> a heat-recoverable sleeve having an interior adhesive lining, the sleeve comprising:
> a first portion at least partially recovered onto an exterior surface of the shell adjacent the open end, retaining the sleeve on the connector; and
> a second portion extending beyond the open end in a substantially unrecovered state, defining an open bell through which the conductors are insertable into the connector without displacing the sleeve;
> wherein, upon application of heat after installation of the connector onto the conductors, the second portion recovers onto the conductors and the adhesive lining forms a continuous environmental seal from the shell to the conductors.

## Independent claim 2 — apparatus (Concept B anchor geometry)

> 2. A twist-on wire connector comprising a molded shell having an internal tapered cavity and a conductive spring, the shell further comprising an annular retention formation on an exterior skirt portion, the retention formation having an inclined lead-in surface and a transverse retention surface dimensioned to mechanically retain a heat-recoverable sealing sleeve against axial displacement during rotational installation of the connector.

## Independent claim 3 — method

> 3. A method of forming a sealed electrical connection, comprising:
> providing a connector assembly per claim 1 as a unitary article;
> inserting stripped ends of a plurality of conductors through the open bell into the connector;
> rotating the connector to mechanically and electrically join the conductors; and
> applying heat to recover the second portion onto the conductors and activate the adhesive lining, thereby environmentally sealing the connection and providing strain relief.

## Independent claim 4 — retrofit article (Concept D)

> 4. A sealing adapter for a twist-on wire connector, comprising a collar engageable with an exterior skirt of the connector and a heat-recoverable, adhesive-lined sleeve carried by the collar in a partially unrecovered state defining an open conductor-entry bell…

## Dependent claims (selected)

- 5. …wherein the sleeve has a shrink ratio of at least 3:1 [and separately: at least 4:1].
- 6. …wherein the first portion is recovered onto a cylindrical skirt band of the shell below external grip formations, leaving the grip formations exposed for rotation.
- 7. …wherein the second portion extends at least 15 mm beyond the open end after full recovery onto the conductors.
- 8. …wherein the sleeve carries a thermochromic indicator that changes appearance upon reaching full-recovery temperature.
- 9. …wherein the adhesive lining comprises a hot-melt adhesive having an activation temperature lower than a full-recovery temperature of the sleeve.
- 10. …wherein the shell comprises polyamide and the sleeve comprises cross-linked polyolefin rated for ultraviolet exposure.
- 11. …wherein the recovered inner diameter of the second portion is no greater than 85% of a minimum rated conductor-bundle diameter of the connector.
- 12. (to claim 2) …wherein the retention formation comprises a barb ring having a lead-in surface inclined at 30°–60° and a retention surface substantially perpendicular to the shell axis.
- 13. …wherein the unitary article is configured such that insertion and rotation are performable identically to an unsleeved twist-on connector.

## Drafting instructions for counsel

1. Spec must tell the **problem/solution story**: prior tubing must be threaded onto wires *before* joining; a twist-on connector rotates during install, which known sleeves would obstruct or wind up; the partially-recovered captive state + open bell solves both. This is the §103 defense.
2. Include the full dimension tables from `/CAD_REQUIREMENTS` and the shrink-ratio math from `/ENGINEERING/03` as embodiment support for claims 5, 7, 11.
3. Include ALL of Concepts A, B, D as embodiments (C omitted deliberately — crowded art).
4. Draw method figures directly from the prototype Figure 0–3 sequence.
5. Consider a **design patent** on the shipped-state appearance as cheap supplementary protection, and a CN utility model in parallel (see 04).

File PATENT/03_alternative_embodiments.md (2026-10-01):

# Alternative Embodiments (include in the non-provisional specification)

Every embodiment below should be described and drawn in the spec, even the ones you never intend to build — each one you describe is one a competitor can't cleanly claim or safely use.

## Attachment / retention variants

1. Partial factory pre-shrink tack onto smooth skirt (launch design).
2. Molded annular barb ring / groove on shell skirt (Concept B).
3. Multiple axial ribs or knurling on skirt instead of a ring.
4. Snap-on collar adapter carrying the sleeve (Concept D retrofit).
5. Adhesive bead or double-sided tape band as sole retention.
6. Sleeve mechanically crimped/clamped by a thin metal or plastic ring.
7. Sleeve insert-molded or overmolded onto the shell during shell molding.

## Sleeve variants

8. Dual-wall adhesive-lined polyolefin (primary).
9. Sleeve with internal mastic band instead of full adhesive lining.
10. Stepped-diameter ("top-hat") extruded sleeve: small diameter pre-formed at the nut end, large bell at wire end — reduces required shrink ratio.
11. Semi-transparent sleeve permitting visual inspection of the joint.
12. Thermochromic full-recovery indicator (stripe, dot, or full-body color change).
13. Pre-printed circuit-ID marking surface on the sleeve.
14. Cold-shrink elastomeric sleeve held expanded by a removable core (no heat needed) — important design-around blocker.
15. UV-cure or chemically-activated sealant liner instead of hot-melt.

## Connector variants

16. Standard spring-insert twist-on (primary).
17. Push-in / lever-style connector body with the same captive sleeve system (blocks the WAGO-style design-around — **high value**).
18. Crimp-sleeve connector with captive pre-tacked sleeve.
19. Oversized 3×#10 shell per the WN-XL dimension set.
20. Shell with integral wire-entry strain ribs cooperating with the recovered sleeve.

## Sealing-direction variants

21. Sleeve extending from mid-shell (as prototyped).
22. Full-shell sleeve covering the entire connector including tip.
23. Two-zone sleeve: high-adhesive lower zone on wires, adhesive-free upper zone on shell (cleaner tack process).

## Method variants

24. Heat by open flame, hot-air, induction-heated ferrule, or electrically self-heating conductive layer in the sleeve.
25. Factory pre-application onto pigtail assemblies (harness-level product).

## Kit / packaging embodiments

26. Connector + sleeve supplied unassembled as a kit with alignment feature (fallback if the captive claim is designed around by shipping parts separately).

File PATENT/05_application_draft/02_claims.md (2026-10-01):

# CLAIMS

> Filing note (delete before filing): starts on a new page headed "CLAIMS" preceded by "What is claimed is:". 20 claims total, 3 independent (claims 1, 14, 17) — exactly the count covered by the base filing/search/examination fees, no excess-claims fees. The retrofit-collar and cold-shrink concepts are kept as dependent claims here; they are natural candidates for a later continuation application if the product succeeds.

What is claimed is:

**1.** A sealable electrical connector assembly comprising:
a wire connector comprising an insulating shell having an open end for receiving a plurality of electrical conductors and a cavity in which the conductors are mechanically and electrically joined; and
a recoverable sleeve having an interior sealant lining, the sleeve comprising:
a first portion retained on an exterior surface of the shell such that the sleeve is captive on the connector; and
a second portion extending beyond the open end in a substantially unrecovered state and defining an open entry bell having an inner diameter greater than an outer diameter of the shell at the open end, such that the conductors are insertable through the second portion into the cavity, and the connector is installable on the conductors, without displacing the sleeve;
wherein the second portion is recoverable onto the conductors after installation such that the sealant lining forms a continuous environmental seal between the shell and the conductors.

**2.** The assembly of claim 1, wherein the wire connector is a twist-on wire connector comprising a helical spring disposed in the cavity, and wherein the first portion retains the sleeve against rotation relative to the shell such that the sleeve rotates with the connector during rotational installation.

**3.** The assembly of claim 1, wherein the sleeve is heat-recoverable and the first portion is partially heat-recovered onto the exterior surface of the shell, the second portion remaining substantially at an as-supplied diameter.

**4.** The assembly of claim 3, wherein the sealant lining comprises a hot-melt adhesive having an activation temperature below a full-recovery temperature of the sleeve, and wherein the hot-melt adhesive within the first portion is not fully activated in the as-supplied state.

**5.** The assembly of claim 1, wherein the shell comprises external grip formations, and the first portion is retained on a substantially cylindrical skirt band of the shell located between the grip formations and the open end, leaving the grip formations exposed.

**6.** The assembly of claim 1, wherein the sleeve has a diametral shrink ratio of at least 3:1.

**7.** The assembly of claim 6, wherein the sleeve has a diametral shrink ratio of at least approximately 4:1.

**8.** The assembly of claim 1, wherein a fully recovered inner diameter of the second portion is no greater than approximately 85% of a diameter of a smallest conductor bundle the connector is rated to receive.

**9.** The assembly of claim 1, wherein the second portion is dimensioned to extend, after full recovery onto the conductors, at least approximately 15 mm beyond the open end along the conductors.

**10.** The assembly of claim 1, wherein the sleeve carries a thermochromic indicator that changes appearance upon reaching substantially a full-recovery temperature of the sleeve.

**11.** The assembly of claim 1, wherein the sleeve comprises a stepped-diameter member having a proximal region of smaller diameter retained on the shell and a distal bell region of larger diameter defining the open entry bell.

**12.** The assembly of claim 1, wherein the first portion is retained on the shell by a collar engaged with an exterior skirt of the shell, the collar carrying the sleeve.

**13.** The assembly of claim 1, wherein the shell comprises polyamide, the sleeve comprises ultraviolet-stabilized cross-linked polyolefin, and the sealant lining comprises a hot-melt adhesive bonding to polyvinyl chloride, polyethylene, and polyamide.

**14.** A twist-on wire connector comprising:
an insulating shell having an open end, an internal tapered cavity, and an exterior skirt portion adjacent the open end;
a helical spring disposed in the cavity for joining a plurality of conductors upon rotation of the connector; and
an annular retention formation on the skirt portion, the retention formation comprising a lead-in surface inclined relative to a longitudinal axis of the shell and facing away from the open end, and a retention surface facing toward the open end, the retention formation being dimensioned to retain a recoverable sealing sleeve on the skirt portion against axial displacement and against torsion during rotational installation of the connector.

**15.** The connector of claim 14, wherein the lead-in surface is inclined at approximately 30° to 60° to the longitudinal axis and the retention surface is substantially perpendicular to the longitudinal axis.

**16.** The connector of claim 14, further comprising a heat-recoverable, sealant-lined sleeve retained on the skirt portion by the retention formation, a portion of the sleeve extending beyond the open end in a substantially unrecovered state and defining an open conductor-entry bell.

**17.** A method of forming a sealed electrical connection, the method comprising:
providing, as a unitary article, a wire connector having an insulating shell with an open end and a recoverable, sealant-lined sleeve captive on the shell, a portion of the sleeve extending beyond the open end in a substantially unrecovered state and defining an open entry bell;
inserting stripped ends of a plurality of conductors through the open entry bell into the connector;
installing the connector on the conductors to form a mechanical and electrical joint while the sleeve remains captive on the shell; and
thereafter recovering the portion of the sleeve onto the conductors such that the sealant lining forms a continuous environmental seal between the shell and the conductors and the recovered sleeve provides strain relief to the joint.

**18.** The method of claim 17, wherein installing comprises rotating the connector, the sleeve rotating with the shell, and wherein recovering comprises applying heat to the sleeve from a flame, hot-air, or other heat source.

**19.** The method of claim 18, further comprising observing a change in appearance of a thermochromic indicator carried by the sleeve as confirmation that full recovery temperature has been reached.

**20.** The method of claim 17, wherein the plurality of conductors comprises conductors of at least two different wire gauges, and the recovered sleeve and activated sealant lining seal interstices between the conductors of different gauges.

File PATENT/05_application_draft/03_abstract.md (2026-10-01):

# ABSTRACT

> Filing note (delete before filing): starts on a new page headed "ABSTRACT OF THE DISCLOSURE"; single paragraph, 150 words or fewer, no reference numerals in parentheses required (permitted but plain text below omits them per common practice).

A sealable electrical connector assembly includes a twist-on wire connector and a recoverable, sealant-lined sleeve captive on the connector. A first portion of the sleeve is retained on the connector shell, for example by partial factory heat-recovery onto the shell skirt or by a molded annular retention formation. A second portion extends beyond the connector's open end in a substantially unrecovered state, defining an open entry bell through which conductors are inserted and the connector installed exactly as a conventional twist-on connector, the sleeve rotating with the shell. Applied heat then recovers the second portion onto the conductors, activating the sealant lining to form a continuous moisture seal between shell and conductors while providing strain relief. Embodiments include a thermochromic full-recovery indicator, a stepped-diameter sleeve, a retrofit collar for standard connectors, and elastically recoverable sleeves.

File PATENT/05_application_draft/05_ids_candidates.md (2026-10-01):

# Information Disclosure Statement (IDS) — Candidate References

File on form **PTO/SB/08a** within 3 months of filing (no fee in that window). List everything below that you actually know of; add anything else you've seen (competitor products, videos, forum posts that showed the idea). Disclosing art does NOT hurt you — it strengthens the patent against later challenges; *withholding* known art can render the patent unenforceable.

## US patents / publications (locate exact numbers via Google Patents before filling SB/08)

Search these on patents.google.com and record the patent numbers of the closest 5–10 hits:

| Search | Why relevant |
|---|---|
| `"twist-on wire connector" sealant` (assignee: King Technology / King Innovation) | Gel-filled DryConn family — closest commercial art |
| `wire connector silicone filled waterproof` (assignee: Ideal Industries, Gardner Bender) | Pre-filled sealant connectors |
| `direct bury splice kit wire connector tube` (assignee: 3M) | DBY/DBR two-piece gel tube + wire nut |
| `heat shrink solder sleeve` / `heat-shrinkable crimp splice adhesive` (TE Connectivity, Raychem) | Adhesive-lined shrink on crimp splices — the "known for crimps" art |
| `"wire nut" "heat shrink"` (all) | Any direct combination — MUST be checked and cited if found |
| CPC class browsing: **H01R 4/22** (twisted-wire connections), **H01R 4/72** (heat-shrink connections), **H02G 15/18** (cable sealing sleeves) | The two classes our claims straddle |

## Non-patent literature (NPL) to list

| Reference | Detail for SB/08 |
|---|---|
| King Innovation "DryConn" product pages / datasheets | Waterproof gel-filled twist connectors (retrieve current URL + access date) |
| 3M DBY-6 / DBR-6 Direct Bury Splice Kit datasheet | Wire nut + gel tube kit |
| Ideal Industries "WeatherProof" wire connector datasheet | Pre-filled connector |
| TE Connectivity ES2000 / dual-wall adhesive tubing datasheet | 4:1 adhesive-lined tubing (component art) |
| UL 486D Standard for Sealed Wire Connector Systems (title/edition only) | Defines the product category |
| Your own prior disclosures, if any (videos, posts, sales) | **Tell me first** — affects grace-period analysis |

## How to file

1. Fill PTO/SB/08a (patents/pubs) and SB/08b page (NPL) — fillable PDFs from uspto.gov/forms.
2. For NPL, attach a copy of each document (PDF printout of datasheet pages is fine). US patents don't need copies.
3. Patent Center → your application → "Upload documents" → doc code **IDS** (+ **NPL** for the attachments).
4. Certification section on SB/08: leave blank (not needed inside the free 3-month window).

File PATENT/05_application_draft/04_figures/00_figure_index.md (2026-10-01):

# Figure Index & Drawing Preparation Notes

## Figures

| File | Figure | Shows | Key numerals |
|---|---|---|---|
| fig1_exploded.svg | FIG. 1 | Exploded view: connector, sleeve, conductors | 10, 20, 22, 24, 28, 30, 32, 40, 42, 44, 46, 48, 50, 52, 54 |
| fig2_shipped_section.svg | FIG. 2 | Shipped state, longitudinal section: tack zone + open bell | 22, 24, 26, 28, 30, 32, 40, 42, 44, 46, 48 |
| fig3_installed_section.svg | FIG. 3 | Installed/sealed state, section: recovered sleeve, fillet, seal region | 20, 40, 42, 44, 50, 60, 62 |
| fig4_anchor_ring_detail.svg | FIG. 4 | Second embodiment: annular retention formation detail | 22, 24, 30, 42, 70, 72, 74, 76 |
| fig5_retrofit_collar.svg | FIG. 5 | Third embodiment: snap-on collar carrying sleeve | 20, 30, 40, 44, 46, 80, 82 |
| fig6_method_sequence.svg | FIGS. 6A–6D | Method: insert, rotate, heat, sealed | 10, 32, 44, 50, 60, 110 |
| fig7_stepped_sleeve.svg | FIG. 7 | Stepped-diameter sleeve variant | 20, 44, 46, 100 |
| fig8_indicator.svg | FIG. 8 | Thermochromic recovery indicator variant | 20, 40, 42, 44, 90 |

## Converting to filing drawings

1. USPTO accepts **informal drawings at filing** — these SVGs, exported to PDF, are adequate to secure the filing date. The examiner may later require formal drawings (a "corrected drawings" requirement); corrections are routine and can be done then.
2. Export: open each SVG in a browser → print to PDF at US Letter, portrait, leaving ≥ 2.5 cm top margin and ≥ 1 cm sides/bottom (37 CFR 1.84 margins). Combine into one `drawings.pdf`, one figure per sheet (FIG. 6A–6D may share one sheet).
3. Rules kept by these drawings: black lines only, no shading/color, reference numerals with lead lines, figure labels "FIG. n".
4. Small text notes inside fig4 ("toward open end 24", "30°–60°") and fig7 ("step") are permitted descriptive text but may be removed if an examiner objects.
5. If you later want polished formal drawings, any patent-drawing service (typically $25–40/sheet) can redraw from these SVGs plus the CAD model in `/CAD_REQUIREMENTS`.

## Consistency rule

Every numeral used in a figure must appear in the Detailed Description, and vice versa — verified against the reference index at the end of `01_specification.md`. If you edit the spec, re-check.

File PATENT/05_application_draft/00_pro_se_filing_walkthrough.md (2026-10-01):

# Pro Se Filing Walkthrough — US Non-Provisional Utility Application

You are filing this yourself ("pro se" — self-represented). That is completely legal and the USPTO supports it. **Scope note, once:** I'm an AI drafting assistant, not a registered patent practitioner, and this isn't legal advice. The two places pro se filers most often get hurt are (1) claim scope decisions during examination and (2) missed deadlines — every deadline below gets a calendar instruction. Free human backstops if you ever want them: the **USPTO Pro Se Assistance Program** (dedicated examiners, free: uspto.gov → "Pro se assistance") and the **Patent Pro Bono Program** (free attorney for qualifying inventors: uspto.gov → "Pro bono").

---

## STEP 0 — Pre-filing checklist (do all of these first)

- [ ] **Find your provisional application number and filing date** (format 63/XXX,XXX, on your provisional filing receipt). Your non-provisional MUST be filed **on or before the 12-month anniversary of that date** or the priority claim dies. → **Calendar the anniversary date now, plus reminders at −60 and −30 days. Target actually filing at least 2 weeks early.**
- [ ] **Send me the provisional's text.** I will check that everything claimed here is supported by it; features the provisional doesn't describe (likely: the pre-tacked captive state, anchor ring, indicator stripe) simply get the non-provisional's filing date instead — fine, but we should know which is which before filing.
- [ ] **Do not publicly disclose, sell, or offer the product** before this filing beyond what's already happened. If any public disclosure/sale happened, tell me the date — the US gives a 1-year grace period from first disclosure, which may be an earlier deadline than the provisional anniversary.
- [ ] **Determine your entity status** (sets fees):
  - **Micro entity** (75–80% discount): you qualify if ALL are true — (a) you qualify as a small entity; (b) you've been named on **4 or fewer** prior non-provisional US applications; (c) your gross income last year was **less than 3× the US median household income** (threshold updates yearly — check the number on the USPTO micro entity page); (d) you haven't assigned/licensed to a non-qualifying entity. Most first-time solo inventors qualify.
  - **Small entity** (50–60% discount): individual / company under 500 employees, not licensed to a large company.
- [ ] Fill every **[PLACEHOLDER]** in `01_specification.md` and `06_forms_and_fields.md` (name, address, citizenship, provisional number/date, title choice).

## STEP 1 — Fees (verify amounts at uspto.gov/fees before paying)

Per the USPTO fee schedule in effect January 2025 — **verify current amounts the week you file**, they adjust periodically:

| Fee | Undiscounted | Small | Micro |
|---|---|---|---|
| Basic filing (utility, electronic) | $350 | $140 | $70 |
| Search | $770 | $308 | $154 |
| Examination | $880 | $352 | $176 |
| **Total due at filing** | **$2,000** | **$800** | **$400** |

- Our claim set is exactly **20 claims / 3 independent** — no excess-claims fees. If you add even one claim, fees apply ($200/$80/$40 per claim over 20; $600/$240/$120 per independent over 3).
- **File the specification/claims/abstract in DOCX format** in Patent Center. Filing those as PDF instead triggers a **non-DOCX surcharge** (~$400/$160/$80). Drawings are always filed as PDF — no surcharge for that.

## STEP 2 — Prepare the documents

1. **Specification** — take `01_specification.md`, fill placeholders, delete the "note" blocks and the reference-numeral index, convert to a single DOCX: 12-pt font, 1.5 or double spacing, paragraph numbers [0001]… kept as-is. Order inside ONE document: Specification → Claims (new page, from `02_claims.md`, delete its note block) → Abstract (new page, from `03_abstract.md`).
2. **Drawings** — export the 8 SVGs to one PDF per the instructions in `04_figures/00_figure_index.md`.
3. **ADS (Application Data Sheet)** — filled in Patent Center's web form; the field-by-field contents are in `06_forms_and_fields.md`. **This is where the provisional priority claim lives. Triple-check it.**
4. **Inventor declaration** — form AIA/01 (download from uspto.gov/forms), fill per `06_forms_and_fields.md`, sign, save as PDF.
5. **Micro entity certification** — form SB/15A (gross income basis), sign, PDF. (Skip if filing as small entity — small entity is just a checkbox assertion, no form.)

## STEP 3 — Patent Center, screen by screen

1. Create a **USPTO.gov account** (uspto.gov → Patent Center → "Sign in" → create account; verify email, set up 2FA).
2. Patent Center → **"New submission" → "Utility — Nonprovisional Application under 35 USC 111(a)"**.
3. **Application data**: enter the title exactly as on the specification. You are the applicant AND inventor.
4. **Upload documents**, assigning each the right document description (Patent Center auto-detects; correct it if wrong):
   - Specification DOCX → it auto-splits into **SPEC / CLM / ABST** sections — verify all three are recognized on the review screen.
   - Drawings PDF → **DRW**.
   - Declaration PDF → **OATH**.
   - Micro entity cert PDF → **SB15A**.
5. **Web ADS**: fill inventor info, correspondence address, and under **"Domestic Benefit/National Stage Information"**: add row — Prior Application Status: *Pending*; Application Number: *[your 63/ number]*; Filing Date: *[provisional date]*; Continuity Type: **"Claims benefit of provisional (35 USC 119(e))"**. **If this row is wrong or missing, your priority claim fails.** Screenshot it.
6. **Fees screen**: check the micro (or small) entity box; the calculator should show exactly the Step-1 total and $0 excess claims. If it shows claim fees, the claims section was mis-parsed — stop and fix.
7. Pay (card/ACH), **submit**, and save: the **Acknowledgement Receipt** PDF and your new **Application Number (18/XXX,XXX)**.

## STEP 4 — Within 3 months of filing

- [ ] **File the IDS** (Information Disclosure Statement): form SB/08 listing the prior art in `05_ids_candidates.md`, uploaded via Patent Center → "Existing submission". Free if within 3 months. You have a duty of candor to disclose known prior art — DryConn, 3M DBY etc. are things you know about; disclose them. → **Calendar +80 days.**
- [ ] Review the official **Filing Receipt** when it arrives (2–6 weeks): check inventor name spelling, title, and that the 119(e) benefit claim to your provisional appears. Errors → file a corrected ADS promptly.
- [ ] Mark packaging/website "**Patent Pending**" (now legitimate for the non-provisional).

## STEP 5 — What happens next (examination timeline)

| When | What | Your move |
|---|---|---|
| ~2–6 weeks | Filing receipt | Verify (above) |
| ~18 months from provisional date | Application publishes | Nothing (this is normal) |
| **~1.5–3 years** | **First Office Action** (expect rejections — normal; >85% of applications get an initial rejection) | Bring it to me; we analyze the examiner's cited art and draft a response/amendment. Response due in 3 months (extendable to 6 with escalating fees). **Calendar the moment it arrives.** |
| After response rounds | Allowance or final rejection | Allowance → pay issue fee ($1,290 / $516 / $258 — verify) promptly. Final rejection → options: RCE, appeal, or amend |
| Grant | Patent issues | Maintenance fees due at 3.5, 7.5, 11.5 years — **calendar all three now-ish** |

Optional accelerators: **Track One** prioritized examination (decision ~12 months; +$1,800 micro / +$3,600 small — verify) if you need the granted patent fast for enforcement/licensing.

## STEP 6 — Same-window international decisions (from PATENT/04, deadline-linked)

The same 12-month provisional anniversary is the deadline to file a **PCT application** or direct **China filings** claiming priority. Since you're manufacturing in China: a **CN utility model** (~$1–2k with a Chinese agent, grants in under a year) is the single most cost-effective add-on, and it must be decided **before** the anniversary. This one genuinely requires a Chinese patent agency (foreign applicants must use one) — that's a service purchase, not "going to a patent attorney."

---

## Master deadline calendar (fill in and put in your phone now)

| Event | Date |
|---|---|
| Provisional filed | [____] |
| **Non-provisional + PCT/CN deadline** | [____ + 12 months] |
| Target filing date (2-week buffer) | [____] |
| IDS deadline (free window) | [filing + 3 months] |
| Check for filing receipt | [filing + 6 weeks] |

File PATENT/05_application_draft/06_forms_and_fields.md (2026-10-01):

# Forms — Field-by-Field Contents

Fill the [PLACEHOLDERS], then transcribe into the actual forms/web screens. Keep answers IDENTICAL across all documents (name spelling, address) — mismatches cause filing-receipt errors.

## Personal data block (used everywhere)

| Field | Value |
|---|---|
| Inventor legal name | [PLACEHOLDER — full legal name, e.g., Philip Gonzales] |
| Residence (city, state, country) | [PLACEHOLDER] |
| Mailing address | [PLACEHOLDER] |
| Citizenship | [PLACEHOLDER] |
| Email for USPTO correspondence | [PLACEHOLDER] |
| Application title | SEALABLE TWIST-ON WIRE CONNECTOR WITH CAPTIVE HEAT-RECOVERABLE SLEEVE |
| Provisional No. / date | [PLACEHOLDER — 63/XXX,XXX] / [PLACEHOLDER — date] |

## 1. ADS — Application Data Sheet (filled as Patent Center web form, not the PDF)

| Screen section | Entry |
|---|---|
| Inventor Information | Name, residence, mailing address from block above. One inventor (add co-inventors ONLY if someone else contributed to conception of a claim — incorrect inventorship can invalidate the patent) |
| Correspondence Information | Your email; enable e-notification (fastest, and avoids lost mail) |
| Application Information | Title as above; Entity Status: Micro (or Small); Application type: Nonprovisional |
| Representative Information | LEAVE BLANK (pro se) |
| **Domestic Benefit Information** | **Add row: Continuity Type = "Claims benefit of provisional application (35 U.S.C. 119(e))"; Prior Application Number = [63/XXX,XXX]; Filing Date = [date]** |
| Foreign Priority | None |
| Assignee Information | Leave blank (you own it personally) unless you've formed an LLC and want it as applicant — if so, an assignment must be executed and recorded; simplest path: file as inventor-applicant, assign to the LLC later via Assignment Center |

## 2. Declaration — form PTO/AIA/01

| Field | Entry |
|---|---|
| Title of invention | Exactly as above |
| Application "attached hereto" checkbox | Check "the attached application" (you file the declaration with the application) |
| Inventor name, signature, date | Sign by hand or S-signature: `/Philip Gonzales/` style between slashes, typed by you |
| Warning acknowledgments | Read the two statements (you reviewed the application; duty of candor) — they're the legal teeth of the form |

## 3. Micro entity certification — form PTO/SB/15A (gross income basis)

| Field | Entry |
|---|---|
| Application number / filing date | Leave blank at first filing (unknown yet) — Patent Center associates it |
| First named inventor | Your name |
| Certification statements (4) | You certify: small-entity qualification; ≤4 prior filed applications; income < the current 3×-median threshold (check the number at uspto.gov → micro entity); no obligation to assign to a non-qualifying entity |
| Signature | Same S-signature style |

If you don't meet ANY one of the four → file as **small entity** instead (no form; just select Small on the fee screen). Never claim micro if unsure — improper micro claims can taint the patent; small entity costs only ~$400 more at filing.

## 4. What NOT to file

- No "petition" forms, no extension forms, nothing else — the base package is exactly: Spec+Claims+Abstract (DOCX), Drawings (PDF), ADS (web), Declaration (PDF), SB/15A (PDF), fees.
- Do not use the old EFS-Web or mail filing — Patent Center only ($400 paper-filing penalty otherwise... and yes, that's a real fee).

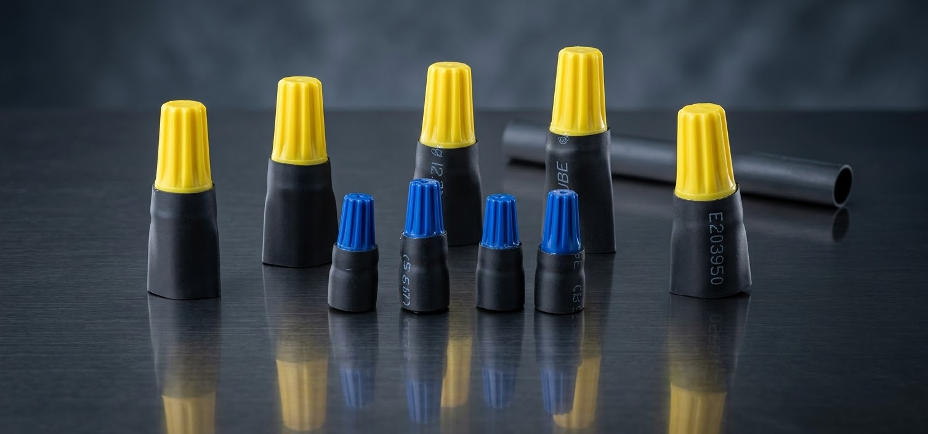
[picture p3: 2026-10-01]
IMAGES/reference_lineup_yellow_blue_sizes.jpg

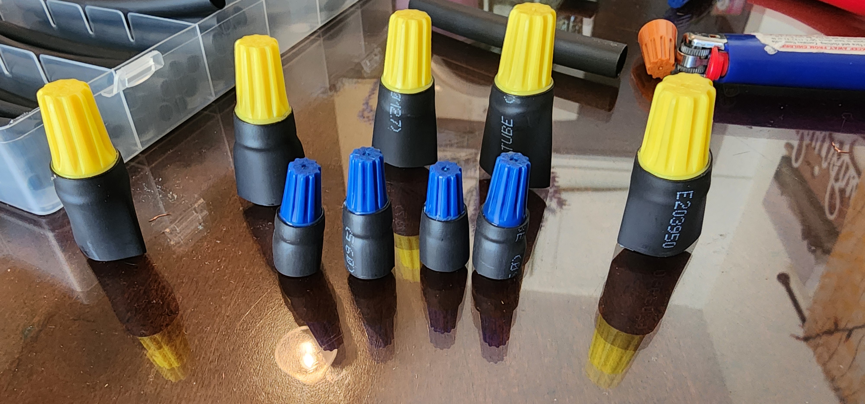
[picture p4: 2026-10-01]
IMAGES/original_lineup_prototypes.jpg

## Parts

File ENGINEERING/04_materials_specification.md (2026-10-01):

# Materials Specification

Status: PRELIMINARY — quantities/grades to be confirmed with supplier datasheets during RFQ.

## M1. Wire nut (purchased component, Concept A)

| Property | Requirement |
|---|---|
| Type | Twist-on wire connector, spring insert, winged or ribbed shell |
| Listing | UL 486C Listed and CSA C22.2 No. 65 certified (require copies of certificates; verify file numbers on UL Product iQ) |
| Shell resin | PA66 (nylon 6/6), flame class UL 94 V-2 or better; **PP shells not accepted** (thermal margin during shrink — see calcs §4) |
| Spring | Square-cross-section spring steel, zinc plated or equivalent corrosion protection |
| Voltage rating | 600 V (building wire), 1000 V signs/luminaires — as marked |
| Temperature rating | 105 °C |
| Sizes | Per SKU table in 02_product_architecture.md |
| Traceability | Lot-marked cartons; certificate of conformance per lot |

## M2. Heat-shrink sleeve

| Property | Requirement |
|---|---|
| Construction | Dual-wall: cross-linked polyolefin outer / hot-melt adhesive inner |
| Shrink ratio | 4:1 (see calcs §2; 3:1 permitted only if min wire config is restricted) |
| Sizes | WN-Y 16/4 mm; WN-R 20/5 mm; WN-XL 24/6 mm (supplied/recovered ID) |
| Recovered wall | ≥ 1.0 mm nominal including adhesive |
| Shrink temperature | Full recovery ≤ 125 °C; onset ≥ 80 °C (shelf/transport stability to 60 °C) |
| Operating temperature | −40 °C to +110 °C minimum (target +125 °C) |
| Outer material specs | Per UL 224 125 °C rated tubing, VW-1 flame rating; UV-resistant, carbon-black ≥ 2% if black |
| Adhesive | EVA or PA-based hot melt; softening point ≥ 90 °C; lap shear ≥ 1.4 MPa to PVC, PE, and PA66 |
| Dielectric strength | ≥ 15 kV/mm (recovered wall) |
| Water absorption | ≤ 0.5% (24 h immersion) |
| Longitudinal change | ≤ ±10% |
| Color | Black (UV baseline). Colored/striped variants require UV qualification per UL 746C f1 |
| Reference equivalents | TE Connectivity ES2000/4:1, Panduit dual-wall 4:1, or qualified Chinese equivalent (Woer, Volsun) with full test reports |

## M3. Optional: thermochromic indicator ink (v2 feature)

- Irreversible color change at 115–125 °C, screen-printed stripe on sleeve exterior.
- Must survive −40…+110 °C service without false trip; UV-stable after trip.

## M4. Packaging materials

| Item | Requirement |
|---|---|
| Inner bag | PE zip bag, 25 or 100 count, printed with size/wire-range table and UL marks (once listed) |
| Instruction insert | Required by UL 486D — installation temperature, heat source guidance, wire strip length, combinations table. English + Spanish for US retail |
| Carton | Double-wall export carton, ISTA-3A drop capable |

## Compliance & restricted substances

- RoHS 3 (EU 2015/863) and REACH SVHC declarations required from all material suppliers.
- California Prop 65: adhesive and tubing declarations required.
- Direct-bury claim (if made) requires materials rated for burial exposure — affects tubing spec and 486D test selections; currently an OPEN QUESTION.

## Incoming-inspection hooks

Every lot of M1 and M2 is accepted per the sampling plan in `/MANUFACTURING/04_quality_control_plan.md` (dimensions, shrink-ratio verification coupon, adhesive presence, UL marking).

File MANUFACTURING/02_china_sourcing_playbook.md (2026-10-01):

# China Sourcing Playbook

Ordered checklist for taking this package to Chinese manufacturers safely.

## Step 0 — IP protection BEFORE any factory contact (non-negotiable order)

1. **File the non-provisional US application** (or at minimum confirm your provisional fully describes what you'll disclose — anything you show a factory that isn't in the provisional is unprotected disclosure).
2. **Decide on China filing within the 12-month priority window**: a PCT application preserves the option; a direct CN utility-model application (fast, cheap, ~7–12 months to grant) gives you an enforceable right *in China* — the only thing a Chinese court cares about. Many US inventors file US non-provisional + CN utility model simultaneously.
3. **NNN agreement** (Non-disclosure, Non-use, Non-circumvention) with EVERY factory before sending drawings:
   - Governed by **Chinese law**, litigated in the **factory's local court**, written in **Chinese** (bilingual OK, Chinese controls), with **liquidated damages** in RMB.
   - A US-law NDA is effectively unenforceable against a Chinese factory. Use a China-specialist firm (e.g., the kind that publishes on China Law Blog) — budget $1.5–3k for a reusable template.
4. **Mold/tooling ownership agreement** (separate or clause): you own the mold, factory may not use it for others, mold released to you on demand. Photograph and serial-number tools.
5. Register your **trademark in China (and US)** now — China is first-to-file; brand squatting is routine.

## Step 1 — Supplier identification (target 8–10 candidates → quote 3–5)

- Categories to search: "heat shrink terminal", "waterproof wire connector", "cable accessories", "wire nut manufacturer".
- Channels: Alibaba (filter: Verified + assessed reports), Global Sources, Canton Fair (Phase 1 electronics), HKTDC.
- Known credible heat-shrink makers to benchmark quality/spec language against: Woer (SZ), Volsun, Suzhou Feibo. Wire-nut clusters: Yueqing, Zhejiang.
- Disqualifiers: no UL file for any product, trading company posing as factory (ask for business license — 营业执照 — and check scope), refuses NNN.

## Step 2 — RFQ

- Send `/MANUFACTURING/03_rfq_template.md` + drawing package (only after NNN).
- Ask every factory the same 12 questions (in template) so answers are comparable.
- Expect FOB unit pricing at 3 volume breaks + tooling/fixture NRE + sample cost/time.

## Step 3 — Sampling & qualification

1. "Golden sample" round: 50–100 units/SKU built to spec.
2. You run (or pay a lab to run) the acceptance subset of `/TESTING/01_validation_test_plan.md` (immersion, pull, tack retention).
3. Iterate DFM: expect the factory to push back on tack process window — that feedback is valuable; capture changes as drawing revisions.
4. Approve and **retain sealed golden samples** (you keep 2 sets, factory keeps 1 signed set) — all future QC disputes settle against these.

## Step 4 — Pilot PO & third-party QC

- Pilot PO 25–50k with 30% deposit / 70% after passed inspection (never 100% up front).
- Book third-party pre-shipment inspection (QIMA, SGS, TÜV, V-Trust; ~$300/man-day): AQL sampling per `/MANUFACTURING/04_quality_control_plan.md`, photos, function tests on site.
- Payment trigger = passed inspection report, not factory say-so.

## Step 5 — Logistics & import

- Incoterms: **FOB** named port (factory loads, you control freight) — avoid EXW (you handle China inland) and CIF (factory controls/pads freight).
- Freight forwarder with US customs brokerage (e.g., Flexport-style or traditional).
- HTS classification: twist-on connectors typically fall under 8536.90 (connection devices ≤1kV) — confirm with broker; Section 301 tariffs may apply, budget landed cost accordingly.
- US import compliance: UL mark only after listing is granted; "Patent Pending" marking on packaging is fine and recommended.

## Step 6 — Ongoing protection

- Split knowledge if possible at scale: tubing converter ≠ final assembler (no single factory holds the full recipe + customer list).
- Record CN customs IP registration once CN patent/TM grants — enables seizure of knock-off exports at the Chinese border.
- Monitor Alibaba/Amazon for clones from month 1 (saved searches for "waterproof wire nut heat shrink").

## Budget summary (typical)

| Item | Est. cost |
|---|---|
| NNN + tooling agreement (law firm) | $2–4k |
| US non-provisional (attorney-drafted) | $8–15k |
| CN utility model or PCT entry | $2–5k |
| Samples + shipping | $500–1.5k |
| Third-party inspections | $300–600/shipment |
| UL 486D listing program | $15–40k (see /TESTING/02) |
| Pilot PO (50k units × ~$0.15) | ~$7.5k |

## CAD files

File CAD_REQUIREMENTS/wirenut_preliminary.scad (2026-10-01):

// ============================================================
// Waterproof Heat-Shrink Wire Nut — PRELIMINARY parametric model
// Status: reference geometry only. NOT for tooling.
// Encodes the target dimensions from 02_critical_dimensions_and_tolerances.md
// so the CAD contractor starts from numbers, not a sketch.
//
// Render examples:
//   openscad -D 'sku="Y"'  -o wnw-y.stl  wirenut_preliminary.scad
//   openscad -D 'sku="XL"' -D 'show_state="installed"' -o wnw-xl.stl wirenut_preliminary.scad
// ============================================================

sku = "XL";              // "Y" | "R" | "XL"
show_state = "shipped";  // "nut_only" | "shipped" | "exploded" | "installed"
concept_b_anchor = false; // true = add molded shrink-anchor barb ring (Concept B)

$fn = 96;
in = 25.4;

// ---- SKU dimension table [mm] ------------------------------
// [base_od, height, tip_od, bore_base, sleeve_id, sleeve_len, tack_len, wall_supplied]
dims =
  sku == "Y"  ? [0.540*in, 0.960*in, 0.150*in, 0.180*in, 16.0, 30.0, 6.0, 0.6] :
  sku == "R"  ? [0.630*in, 1.050*in, 0.180*in, 0.220*in, 20.0, 33.0, 6.0, 0.65] :
                [0.720*in, 1.200*in, 0.200*in, 0.260*in, 24.0, 36.0, 7.0, 0.7];

base_od   = dims[0];
height    = dims[1];
tip_od    = dims[2];
bore_base = dims[3];
sleeve_id = dims[4];
sleeve_len= dims[5];
tack_len  = dims[6];
sleeve_wall = dims[7];

taper_deg   = 6.5;        // internal taper (per side)
skirt_band  = (sku=="XL") ? 7.0 : 6.0;  // cylindrical tack landing at base
wing_count  = 2;
shell_wall  = 1.5;

// ---- Wire nut shell (purchased-part envelope) --------------
module wirenut() {
  color("goldenrod")
  difference() {
    union() {
      // cylindrical skirt band (tack landing)
      cylinder(h = skirt_band, d = base_od);
      // conical body above skirt
      translate([0,0,skirt_band])
        cylinder(h = height - skirt_band, d1 = base_od, d2 = tip_od);
      // simplified grip wings (kept above tack zone)
      for (a = [0 : 360/wing_count : 359])
        rotate([0,0,a])
          translate([0, 0, skirt_band + 1.0])
            wing();
      // Concept B: annular barb anchor ring on skirt
      if (concept_b_anchor) anchor_ring();
    }
    // internal tapered bore (spring cavity envelope):
    // bore_base at entry, narrowing at taper_deg per side
    translate([0,0,-0.1])
      cylinder(h = height - shell_wall + 0.1,
               d1 = bore_base,
               d2 = max(0.5, bore_base - 2*(height - shell_wall)*tan(taper_deg)));
  }
}

module wing() {
  // simplified external grip rib
  linear_extrude(height = height*0.55, scale = 0.6)
    translate([base_od/2 - 1, 0])
      square([2.5, 3.0], center = true);
}

module anchor_ring() {
  // Concept B barb: 45 deg lead-in, 90 deg retention face
  crest_od = base_od + 1.6;
  translate([0,0,skirt_band*0.4])
    rotate_extrude()
      polygon([
        [base_od/2 - 0.01, 0],
        [crest_od/2, 1.2],      // 45-ish lead-in up to crest
        [base_od/2 - 0.01, 1.2] // square retention face
      ]);
}

// ---- Heat-shrink sleeve -------------------------------------
// shipped: upper tack zone recovered ~40% onto skirt, bell open below
module sleeve(installed=false) {
  tack_id = base_od + 0.2;                 // tacked snug on skirt
  color("dimgray", 0.85)
  if (!installed) {
    union() {
      // tack zone on skirt
      translate([0,0,0])
        tube(h = tack_len, id = tack_id, wall = sleeve_wall*1.4);
      // transition + open bell hanging below nut base
      translate([0,0,-(sleeve_len - tack_len)])
        tube(h = sleeve_len - tack_len, id = sleeve_id, wall = sleeve_wall);
    }
  } else {
    // recovered onto a 3-wire bundle (display only)
    bundle_d = 2.155 * 4.2; // 3 x #10 THHN approx
    union() {
      tube(h = tack_len, id = tack_id, wall = sleeve_wall*1.4);
      translate([0,0,-(sleeve_len*0.9 - tack_len)])
        cylinder(h = sleeve_len*0.9 - tack_len,
                 d1 = bundle_d + 2*1.0 + 2*sleeve_wall,
                 d2 = tack_id + 2*sleeve_wall*1.4);
    }
  }
}

module tube(h, id, wall) {
  difference() {
    cylinder(h = h, d = id + 2*wall);
    translate([0,0,-0.1]) cylinder(h = h + 0.2, d = id);
  }
}

// ---- Wire bundle (display) ----------------------------------
module wires(n = 3, d = 4.2, len = 40) {
  color("black")
  for (i = [0 : n-1])
    rotate([0,0,i*360/n])
      translate([d/1.75, 0, -len])
        cylinder(h = len + 4, d = d);
}

// ---- States --------------------------------------------------
if (show_state == "nut_only") {
  wirenut();
} else if (show_state == "shipped") {
  wirenut();
  sleeve(false);
} else if (show_state == "exploded") {
  translate([0,0,25]) wirenut();
  sleeve(false);
  wires();
} else if (show_state == "installed") {
  wirenut();
  sleeve(true);
  wires();
}

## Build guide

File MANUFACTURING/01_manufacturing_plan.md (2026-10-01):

# Manufacturing Plan

## Phase overview

| Phase | Configuration | NRE | Purpose |
|---|---|---|---|
| P1 Pilot (0–50k units) | Concept A, semi-automated | Fixtures only ($2–5k) | Prove tack process, UL samples, first sales |
| P2 Scale (50k–1M) | Concept A, automated cut/tack line | $15–30k line | Cost reduction, retail launch |
| P3 Gen-2 (>1M or on competitive pressure) | Concept B custom nut | $8–25k/size mold + line | Margin + IP moat |

## P1/P2 process flow (Concept A)

```
Purchased nuts (UL 486C listed) ─┐
                                 ├─► [1] Incoming QC (AQL sampling, dims, resin check)
4:1 dual-wall tubing on reels ───┘
        │
        ▼
[2] Tube cut to length (rotary cutter, ±0.5 mm) ── scrap: angled/smeared cuts
        ▼
[3] Sleeve load: nut tip-down on mandrel pallet, sleeve dropped over skirt,
    hard stop sets axial position (tack zone start 1.0 ± 0.5 mm below wing root)
        ▼
[4] Tack: hot-air ring or IR zone, 95–105 °C, 4–8 s
    (upper 6–7 mm recovers ~40% onto skirt; bell stays open)
        ▼
[5] Cooling + 100% visual (position, open bell, no scorch)
    + in-line retention audit (20 N pull, AQL 1.0)
        ▼
[6] Bagging (25/100 ct) + instruction insert + carton
        ▼
[7] Final QC per control plan → FOB
```

Cycle-time target: ≥ 30 assemblies/min on a 6-nest rotary table (P2).

## Injection molding analysis (Concept B / WN-XL contingency)

| Topic | Assessment |
|---|---|
| Part | Single shell, PA66 GF0, ~2–3 g, wall 1.5 mm |
| Mold | 8–16 cavity, hot runner tip gate, P20/H13 steel, 500k–1M shot guarantee |
| Tooling cost (China) | 8-cav ≈ $8–12k; 16-cav ≈ $15–25k per size |
| Cycle | 12–18 s |
| Tricky features | Internal taper core (straight pull — OK); anchor barb ring is an undercut → use a 2-piece stripper ring or snap-eject (PA66 tolerates ~1.6 mm snap-off at skirt dia) — confirm with mold DFM |
| Spring | Purchased tapered square-wire spring, auto-fed press-in station, torque verification 100% or SPC |
| Resin | UL-recognized PA66, V-2, f1 if colored (e.g., Ascend Vydyne, or approved Chinese equivalent with yellow card) |

## Assembly method decisions still open

- Tack heat source: hot-air ring (cheap, wider window) vs IR (faster, tighter control) — decide in P1 trials.
- Whether cut-and-tack happens at the tubing converter or the nut assembler (fewer logistics hops if one factory does everything — target a cable-accessories factory that already buys or molds wire nuts).

## Expected factory type & processes (what to look for in audits)

- Product category: cable accessories / heat-shrink products / wiring devices. Clusters: **Yueqing (Zhejiang)** for wiring devices; **Shenzhen/Dongguan** for heat-shrink converters (Woer, Volsun ecosystems).
- Must have in-house: tube cutting, hot-air/IR process ovens, pull-force tester, hi-pot tester, UL experience (existing UL files strongly preferred).
- Nice to have: injection molding on site (future Concept B), UL 486C/D test fixtures.

## Capacity & logistics assumptions

- MOQ expectation: 25–50k units/SKU initial PO.
- Lead time: samples 2–3 wk; pilot lot 4–6 wk; production 30–45 days ARO.
- Terms: FOB Ningbo/Shenzhen, third-party inspection before release (see QC plan).

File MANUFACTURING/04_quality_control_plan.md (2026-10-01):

# Quality Control Plan

Applies to Concept A production. Sampling per ANSI/ASQ Z1.4 (GB/T 2828.1 equivalent), General Inspection Level II unless noted.

## 1. Incoming inspection (IQC)

### Wire nuts (per lot)

| Check | Method | AQL / rule |
|---|---|---|
| UL mark & model vs spec | Visual vs cert | Reject lot if mismatch |
| Base OD, skirt band height | Caliper, n=13 | AQL 1.0 |
| Shell resin | Supplier CoC + burn/FTIR spot check first 3 lots | PA66 required |
| Spring presence/torque feel | Manual twist on gauge wires, n=5 | 0 defects |

### Heat-shrink tubing (per lot/reel batch)

| Check | Method | AQL / rule |
|---|---|---|
| Supplied ID, wall | Caliper/pin gauge, n=13 | AQL 1.0 |
| Shrink ratio & recovered ID | 150 °C oven coupon, 3 min, n=3 | All must meet recovered spec |
| Adhesive liner present & continuous | Cut cross-section, visual | 0 defects |
| Datasheet lot cert (UL 224) | Document | Required |

## 2. In-process controls (IPQC)

| Station | Control | Reaction plan |
|---|---|---|
| Tube cut | Length ±0.5 mm, squareness ≤1 mm — first article + hourly n=5 | Stop, adjust, re-check last hour bin |
| Sleeve position | Hard-stop fixture; first article per shift + camera or go-gauge | Quarantine since last good check |
| Tack oven | Temp logged continuously 95–105 °C; belt speed locked | Auto-stop on excursion |
| Post-tack | 100% visual: position, open bell, no scorch/bridging | Rework not allowed — scrap |
| Retention audit | 20 N axial pull, n=5/hour | Fail → hold lot, adjust tack, 100% screen last hour |

## 3. Final / outgoing (OQC) — and third-party pre-shipment scope

Sample per Z1.4 GII from packed cartons:

| Class | Defect examples | AQL |
|---|---|---|
| Critical | Missing sleeve; sleeve fully shrunk (bell closed); wrong size in bag; missing UL-required insert | 0 |
| Major | Position out of spec; retention <20 N; scorch; cut length out of tol; illegible print | 1.0 |
| Minor | Cosmetic scuff; bag print offset; carton label errors | 2.5 |

Functional subset during inspection (n=8/SKU): twist onto max wire combo, lighter-shrink per instructions, visual seal continuity; 2 of the 8: 24 h water dip + megger ≥ 100 MΩ (if inspector has equipment; else ship-to-buyer test).

## 4. Golden samples

- 3 signed/sealed sets after first approved lot: buyer ×2, factory ×1.
- All visual disputes settle against golden samples; refresh on any drawing revision.

## 5. Traceability & records

- Each carton: SKU, PO, lot code (nut lot + tubing lot + date + line).
- Factory retains IQC/IPQC/OQC records 3 years; copies with each shipment CoC.

## 6. Epidemic-defect clause (mirror in PO terms)

Field failure of a sealed characteristic (leak at correctly-installed joint, sleeve detachment in packaging) >1% of any lot → factory replaces lot and root-causes with 8D report before next shipment releases.

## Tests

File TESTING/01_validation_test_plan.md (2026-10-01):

# Validation Test Plan

Three tiers: **DV** (design verification, engineering samples), **PV** (production validation, pilot-line units), **OQC** (ongoing, per QC plan). Standards referenced: UL 486C (splicing wire connectors), UL 486D (sealed wire connector systems), UL 224 (tubing). Formal listing tests run at UL/Intertek — this plan is the pre-submission gauntlet so you only pay the lab once.

Sample basis: each test uses the worst-case wire combination (min AND max) per SKU unless noted. Install per draft instructions (butane lighter, per-instruction dwell) — the *instructions* are part of the certified system under 486D.

## A. Mechanical — connection integrity (UL 486C-derived)

| # | Test | Method | Pass criterion | Tier |
|---|---|---|---|---|
| A1 | Pull-out, joint | Tensile on each conductor after install, pre- and post-seal | UL 486C force table (e.g., #10 = 80 lbf, #14 = 50 lbf, #18 = 30 lbf) | DV, PV |
| A2 | Sleeve retention (shipped state) | 20 N axial pull on sleeve | No displacement > 1 mm | DV, OQC |
| A3 | Drop/handling | 10 units × 1 m onto concrete, 3 orientations | Sleeve retained, bell open, installs normally | DV |
| A4 | Torque robustness | Install to 150% typical torque | No sleeve wind-up, tear, or displacement | DV |
| A5 | Flex/strain relief | Installed joint, 90° bend cycles at 25 mm from nut, 30 cycles | No conductor breakage, seal intact (leads to B1) | DV |

## B. Sealing — the product's reason to exist (UL 486D-derived)

| # | Test | Method | Pass criterion | Tier |
|---|---|---|---|---|
| B1 | Water immersion + insulation resistance | Install, seal, immerse 24 h in conductive water (salted), 300 mm head; megger conductor-to-water at 500 VDC | ≥ 50 MΩ (486D-style; target ≥ 100 MΩ) | DV, PV |
| B2 | Immersion cycling | 10× (2 h @ 60 °C air → plunge into 25 °C water 1 h) then B1 | Pass B1 | DV |
| B3 | Long-term immersion | 14-day immersion, energized 12 VAC, then IR | Pass B1 criterion | DV |
| B4 | Under-heating sensitivity | Deliberate 50%/75% recovery samples | Characterize failure signature; informs indicator-stripe decision & instructions | DV |
| B5 | Direct-bury (only if claimed) | 486D direct-burial condition set | Per standard | DV (optional) |

## C. Environmental durability

| # | Test | Method | Pass criterion | Tier |
|---|---|---|---|---|
| C1 | Thermal cycling | −40 °C ↔ +85 °C, 25 cycles, installed samples | Pass B1 after | DV |
| C2 | UV weathering | UV-B 313 nm, 500 h (screen) / outdoor grade per UL 746C f1 (formal) on sealed samples | No cracking; pass B1 | DV |
| C3 | Heat aging | 121 °C × 168 h (tubing, per UL 224 basis) | Elongation retention per 224 | DV (supplier data may cover) |
| C4 | Cold install | Install + shrink at −10 °C | Full recovery, pass B1 | DV |
| C5 | Chemical | 24 h exposure: fertilizer solution, chlorinated pool water, cutting-oil wipe | Pass B1 | DV |

## D. Electrical

| # | Test | Method | Pass criterion | Tier |
|---|---|---|---|---|
| D1 | Dielectric withstand | 2.2 kV 60 s conductor-to-outer-surface wrap (486C basis) | No breakdown | DV, PV |
| D2 | Temperature rise / current cycling | UL 486C static heating + 500-cycle current cycling at rated ampacity on max combo | ΔT and stability limits per 486C | DV (lab) |
| D3 | Low-voltage service soak | 15 VAC, 25 A landscape-transformer circuit, 1000 h outdoors or condensing chamber | No IR degradation | PV (field-representative) |

## E. Usability (informal but decisive for the value proposition)

- 5 landscape contractors + 5 homeowners: timed install vs (a) grease nut, (b) tape+nut, (c) separate heat shrink. Target: ≥ 2× faster than (c), parity with (a), zero failed seals with only the printed instructions.
- Capture heat-source reality: lighter vs torch vs heat gun success rates → feeds instruction wording and the indicator-stripe go/no-go.

## Reporting

Every DV test gets a one-page report: sample config, lot, method, data table, photos, pass/fail, deviation notes. These reports go to the UL submission package and to the factory as the acceptance baseline.

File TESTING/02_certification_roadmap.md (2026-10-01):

# Certification & Compliance Roadmap

## The governing standards

| Standard | Scope | Applies |
|---|---|---|
| **UL 486D** — Sealed Wire Connector Systems | Connectors that make a sealed splice; damp/wet locations, optional direct-bury | **The core listing.** The seal *system* (nut + sleeve + instructions) is certified together |
| UL 486C — Splicing Wire Connectors | The twist-on connection itself | Covered by the purchased nut's existing listing (Concept A) — confirm the listing survives our added sleeve; UL will treat the assembly as a new product under 486D with 486C construction requirements |
| CSA C22.2 No. 188 / No. 65 | Canadian equivalents | Get cUL simultaneously (same test program, small adder) |
| UL 224 | The tubing itself | Supplier's existing recognition (yellow card) — require it in the tubing spec |
| NEC context | NEC 110.14, 300.5(direct bury), Art. 411 (low-voltage lighting) | Determines what claims ("wet location", "direct bury") are worth making |

## Practical path

1. **Pre-submission engineering review with UL or Intertek (ETL)** (~$1–3k): bring this package; agree the test program and whether the purchased nut's 486C listing is leverageable. ETL is typically 20–40% cheaper and faster; UL mark carries more weight at electrical distributors. Decide by channel: big-box retail → either; electrical distribution → UL preferred.
2. Run the DV plan (`01_validation_test_plan.md`) in-house first — failing at the NRTL costs a full resubmission.
3. Formal program: samples from the **pilot production line** (not hand-built), instructions and packaging art included (486D certifies the instructions).
4. Factory audit: the NRTL will inspect and enroll the Chinese factory for follow-up services (quarterly). Factories with existing UL files onboard faster — selection criterion in the RFQ.
5. Marks on packaging only after grant. "Patent pending" allowed immediately; "UL Listed" absolutely not before.

## Cost & time estimate

| Item | Cost | Time |
|---|---|---|
| Pre-submission review | $1–3k | 2–4 wk |
| 486D program, 3 SKUs, + cUL | $15–40k | 3–5 months |
| Factory initial audit + FUS enrollment | $3–6k, then ~$2–4k/yr | parallel |

## Claims ladder (market what you certify, nothing more)

1. Tier 1 (launch): *Wet location, above ground* — landscape lighting sweet spot.
2. Tier 2: *Direct bury* — adds 486D burial conditions; big label value for landscape market. Decide before the test program (adds samples, not a second program).
3. Tier 3: 600 V general splice rating — inherits from nut; opens the broader electrical market.

## Other compliance

- FCC: n/a (passive device).
- CA Prop 65 label evaluation (adhesive/tubing declarations).
- RoHS/REACH: declarations from suppliers (spec'd in materials doc) — needed for EU expansion and increasingly for US retail onboarding.
- Product liability insurance: required by every big-box/distributor vendor agreement (~$2–5k/yr at launch volumes). Do not skip — this is an electrical product in wet locations.

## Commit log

2026-07-10 Add OEM design package: patent, engineering, CAD, manufacturing, testing docs
    Complete pre-CAD design package for the waterproof heat-shrink wire nut:
    - ENGINEERING: concept trade study (A-D), product architecture, sleeve
    sizing/shrink-ratio calculations, materials spec
    - CAD_REQUIREMENTS: BOM, critical dimensions/tolerances (mm primary),
    drawing package requirements, preliminary parametric OpenSCAD model
    - MANUFACTURING: process plan, China sourcing playbook (NNN/IP-first),
    RFQ template, quality control plan
    - PATENT: novelty analysis, draft claims, alternative embodiments,
    design-around and filing strategy
    - TESTING: UL 486D-oriented validation plan, certification roadmap
    - OPEN_QU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
    [wirenut_preliminary.scad]
2026-07-14 Add filing-ready non-provisional patent application draft for pro se filing
    PATENT/05_application_draft/:
    - 00: step-by-step Patent Center pro se filing walkthrough (fees at
    micro/small entity rates, ADS priority-claim instructions, deadline
    calendar, IDS window, post-filing timeline)
    - 01: full 37 CFR 1.77 specification, 3 embodiments (captive pre-tacked
    sleeve, anchor-ring shell, retrofit collar) + variant embodiments and
    dimensional support tables
    - 02: 20 claims (3 independent: apparatus, anchor-ring connector,
    method) sized to avoid excess-claims fees
    - 03: abstract (135 words)
    - 04: FIGS. 1-8 as black-line SVGs with consistent reference numerals
    + figure index and drawing-c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
2026-10-01 Mark prototype images as AI-edited; clarify provenance
    Claude-Session: https://claude.ai/code/session_01RiDMxZ7tRPXbFy6kBkfd43
2026-10-01 Add original prototype photos; correct image notes
    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
